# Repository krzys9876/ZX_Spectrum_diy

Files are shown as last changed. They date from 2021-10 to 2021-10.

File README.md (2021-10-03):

# ZX_Spectrum_diy

All boards that I designed, etched and soldered to create a full-diy replica of ZX Spectrum.
**Kicad4** (just a keyboard) and **Kicad5**

This is NOT a cycle-perfect replica so do not expect to launch fancy demos on it. 
The project started as a breadboard simplest possible computer using Z80. Quite quickly I started thinking of making a replica of ZX Spectrum - the first computer I ever used as a kid. All I wanted was to:

- launch Knight Lore - the best game ever
- write some Basic programs - to feel the magic of programming again - and I did!

Have questions? Just drop me an email.

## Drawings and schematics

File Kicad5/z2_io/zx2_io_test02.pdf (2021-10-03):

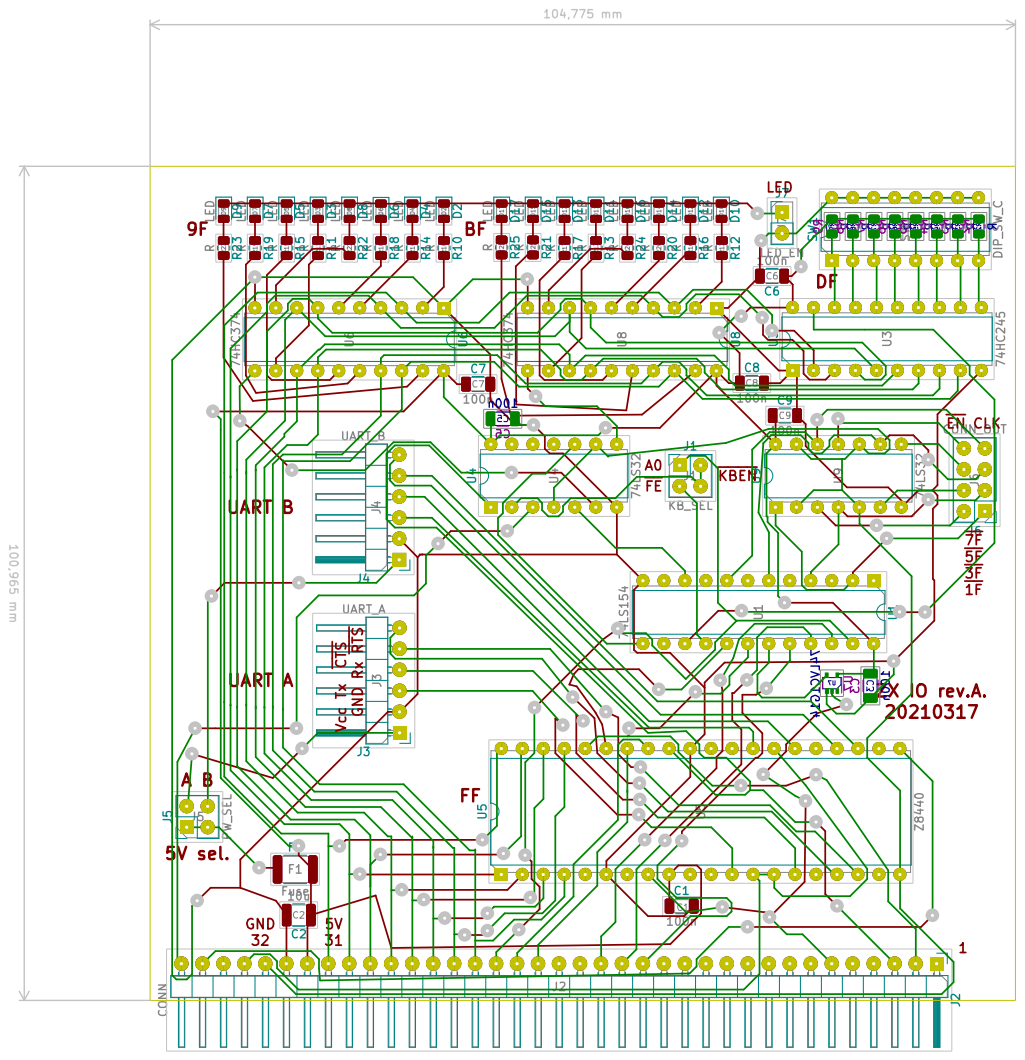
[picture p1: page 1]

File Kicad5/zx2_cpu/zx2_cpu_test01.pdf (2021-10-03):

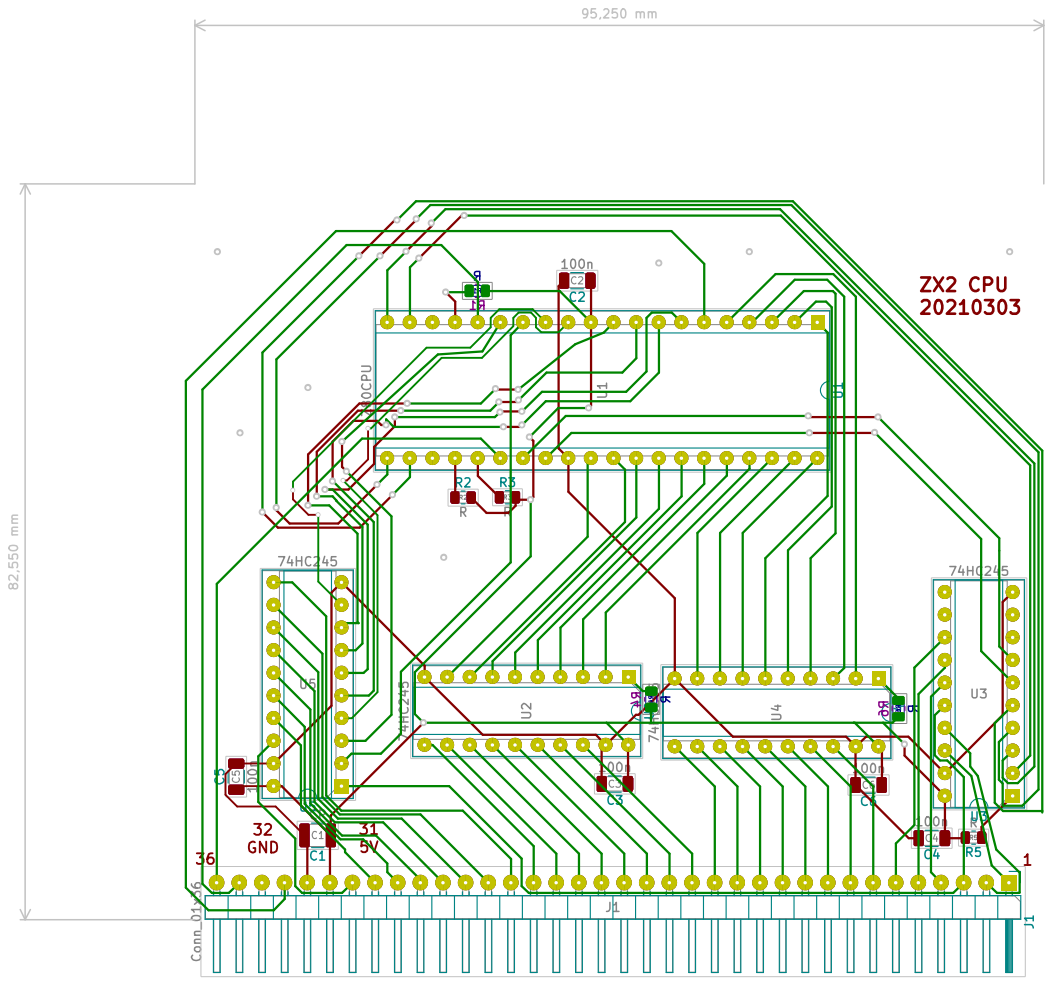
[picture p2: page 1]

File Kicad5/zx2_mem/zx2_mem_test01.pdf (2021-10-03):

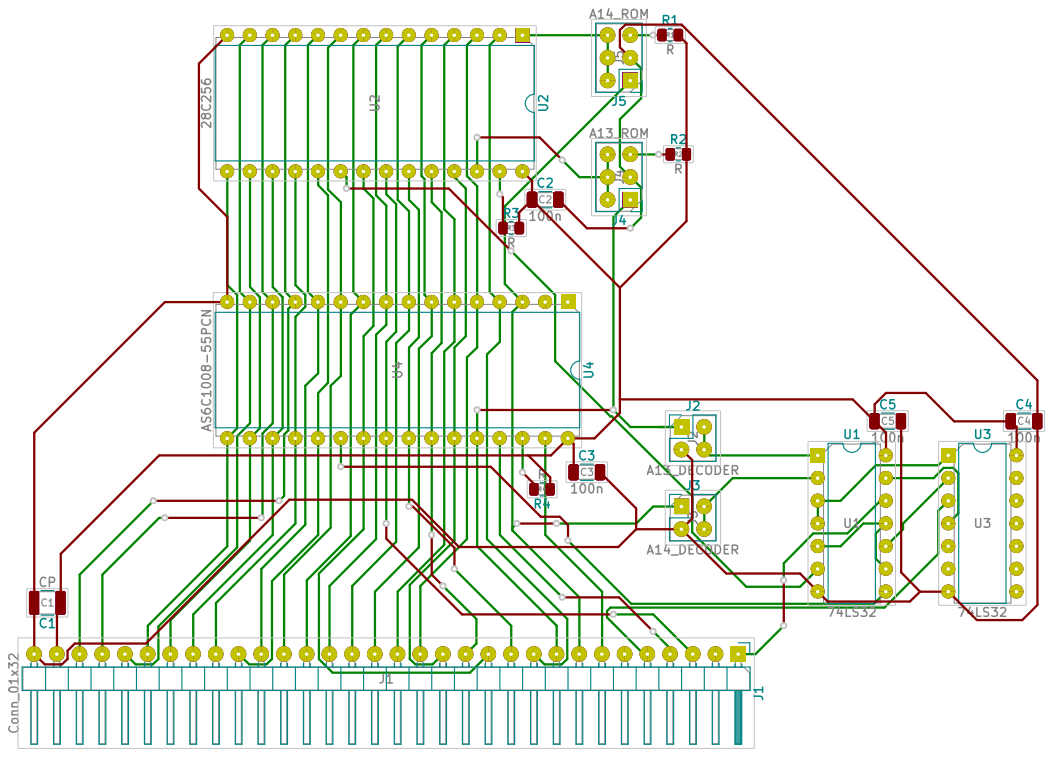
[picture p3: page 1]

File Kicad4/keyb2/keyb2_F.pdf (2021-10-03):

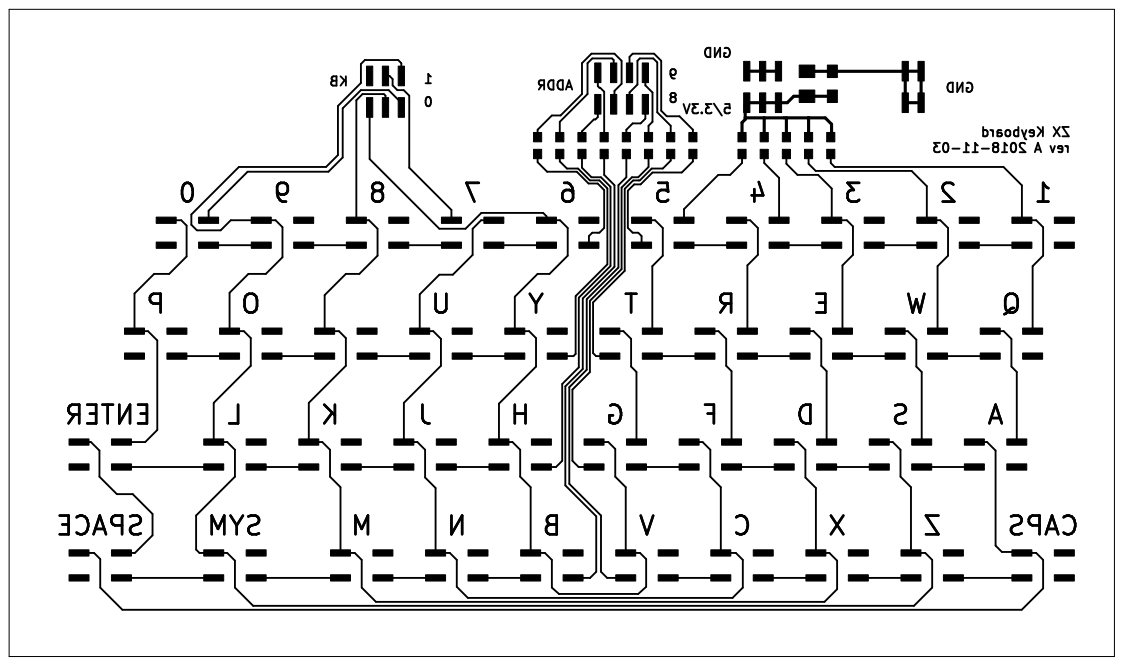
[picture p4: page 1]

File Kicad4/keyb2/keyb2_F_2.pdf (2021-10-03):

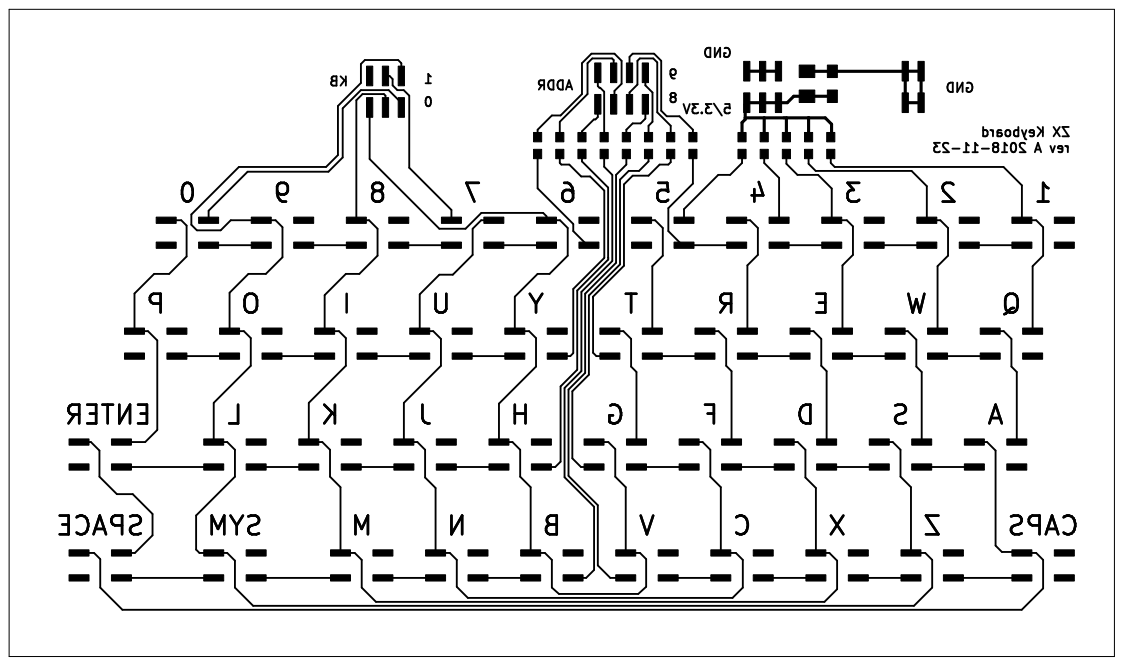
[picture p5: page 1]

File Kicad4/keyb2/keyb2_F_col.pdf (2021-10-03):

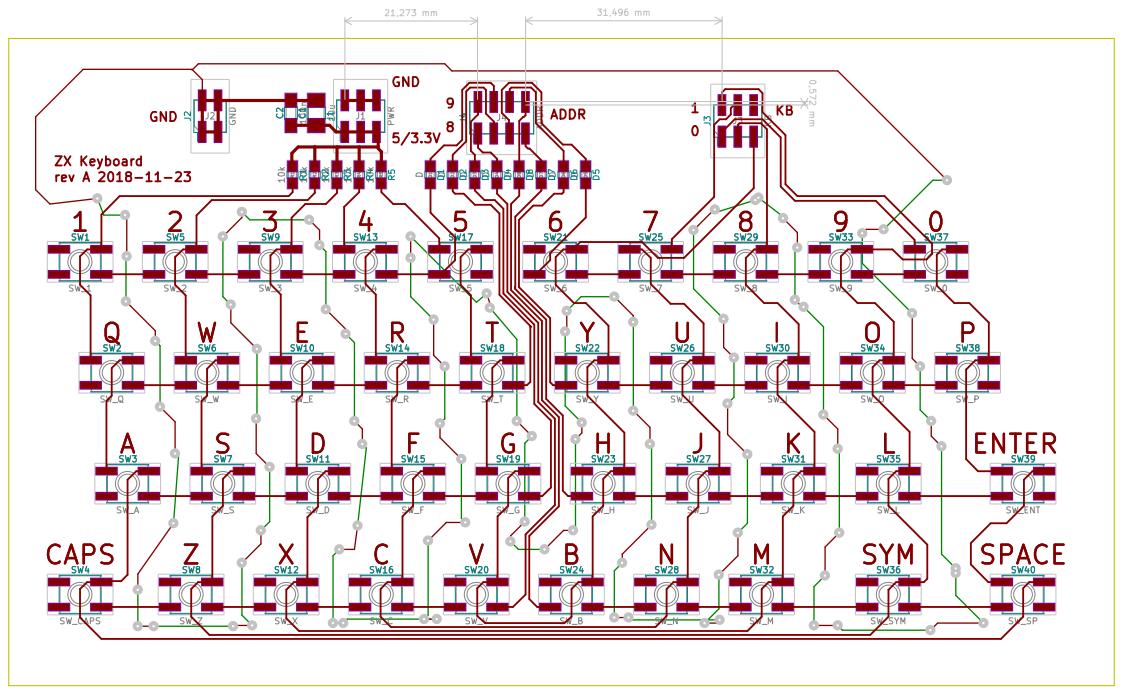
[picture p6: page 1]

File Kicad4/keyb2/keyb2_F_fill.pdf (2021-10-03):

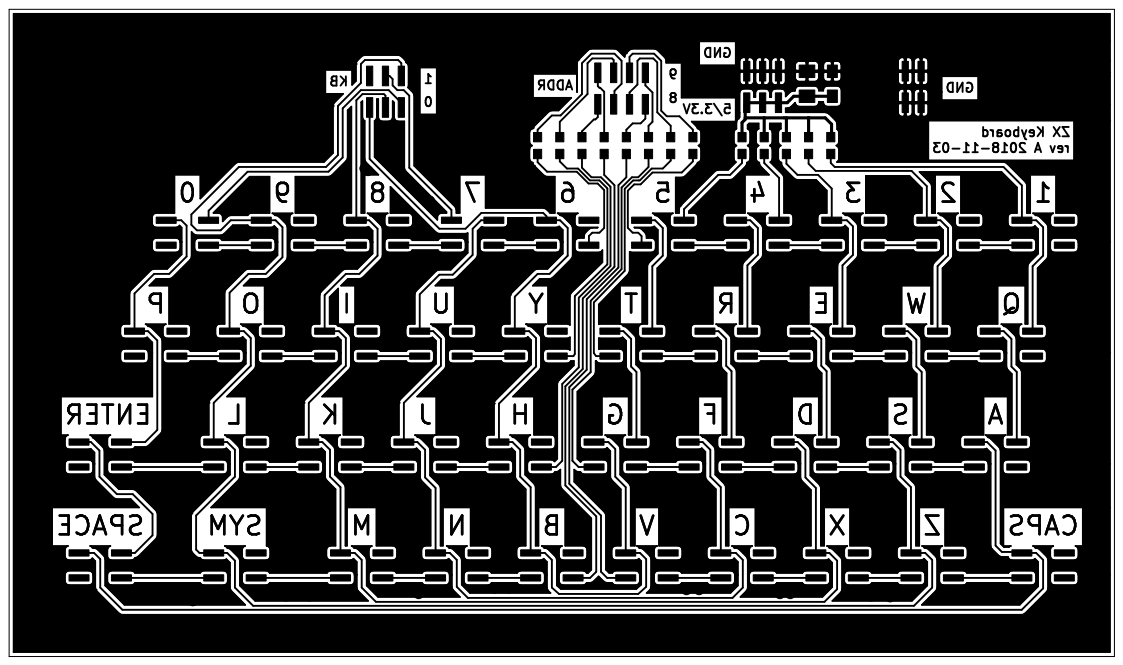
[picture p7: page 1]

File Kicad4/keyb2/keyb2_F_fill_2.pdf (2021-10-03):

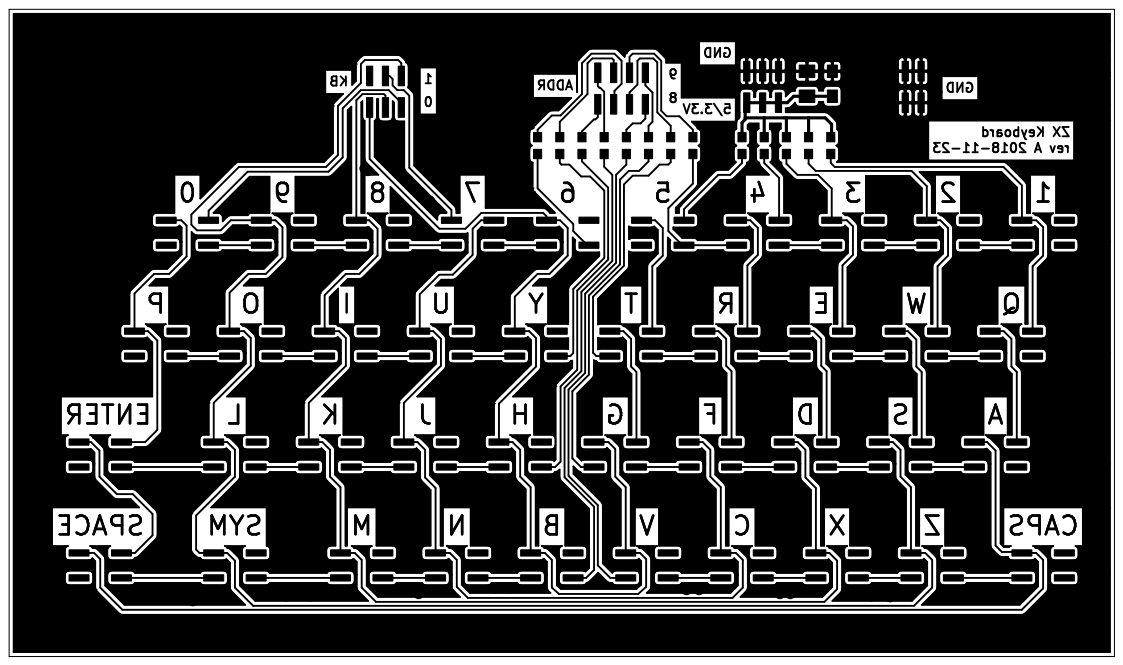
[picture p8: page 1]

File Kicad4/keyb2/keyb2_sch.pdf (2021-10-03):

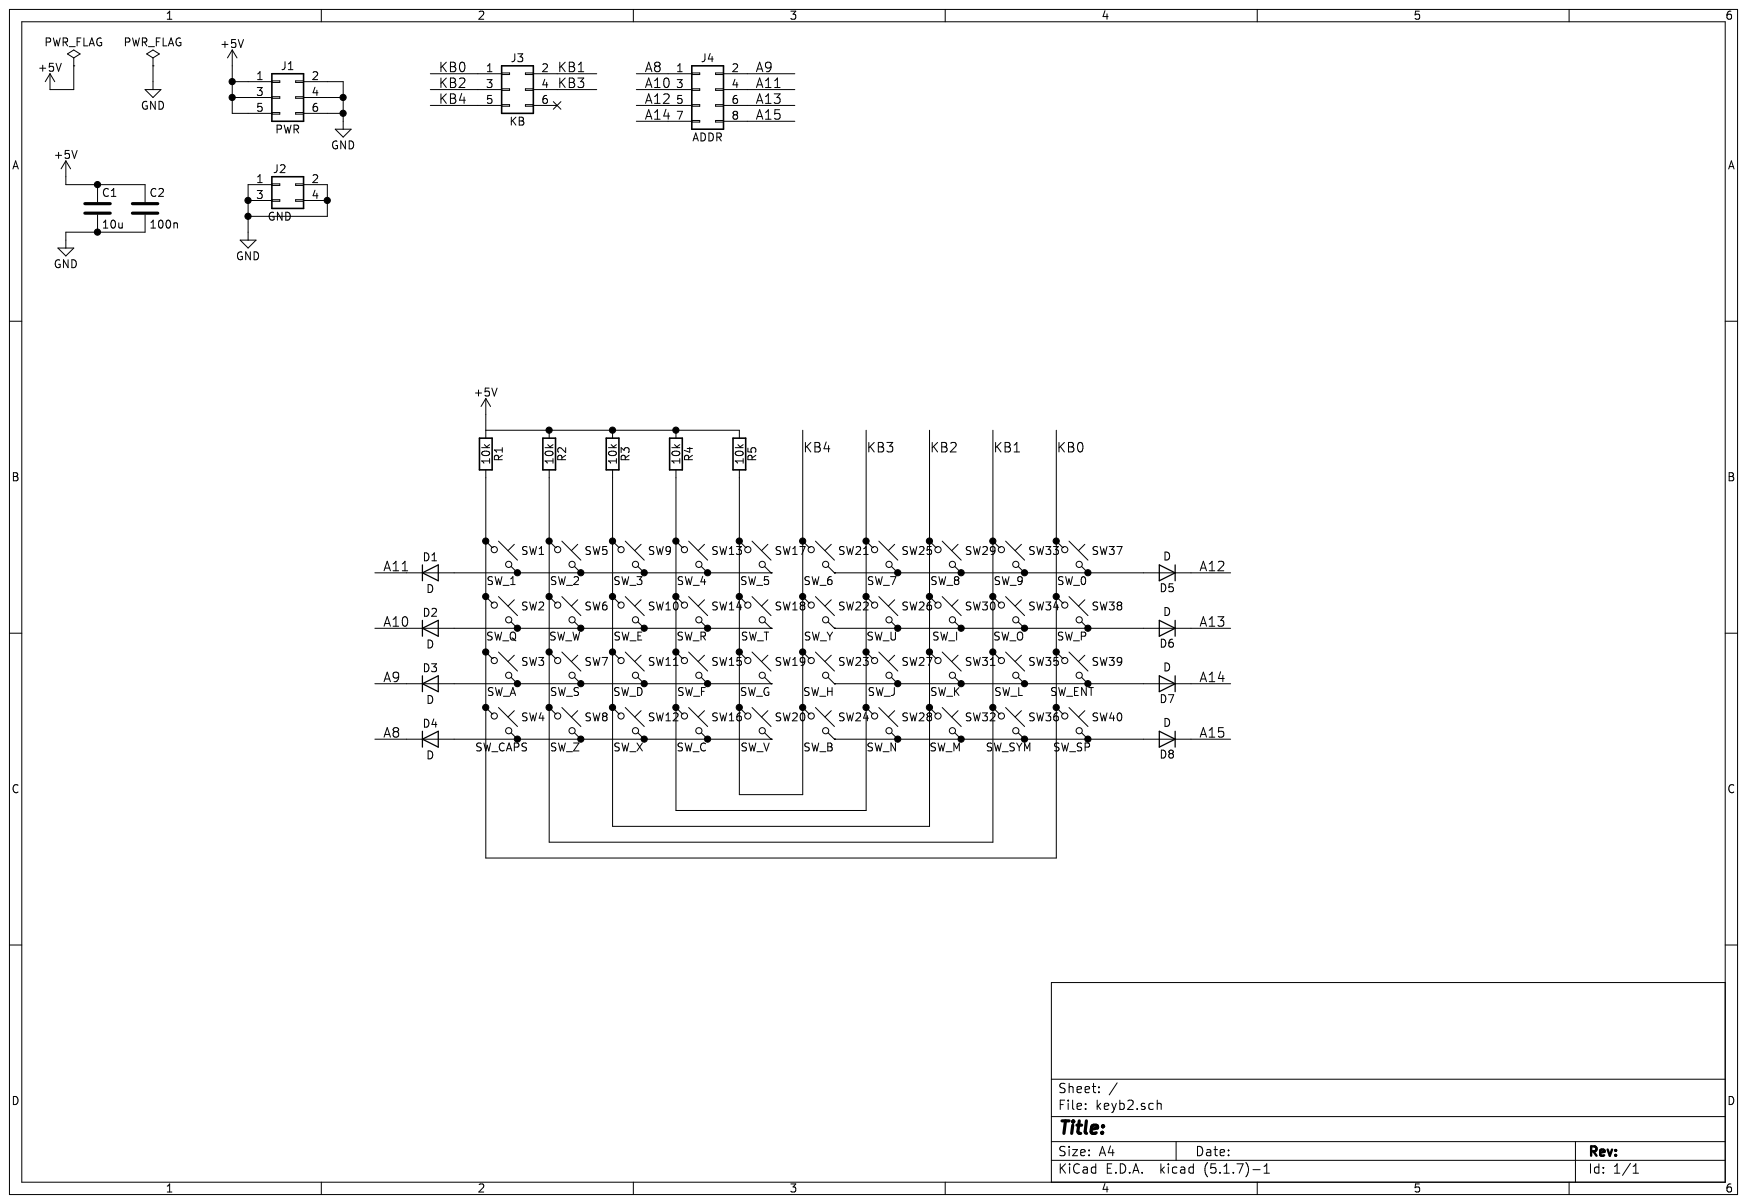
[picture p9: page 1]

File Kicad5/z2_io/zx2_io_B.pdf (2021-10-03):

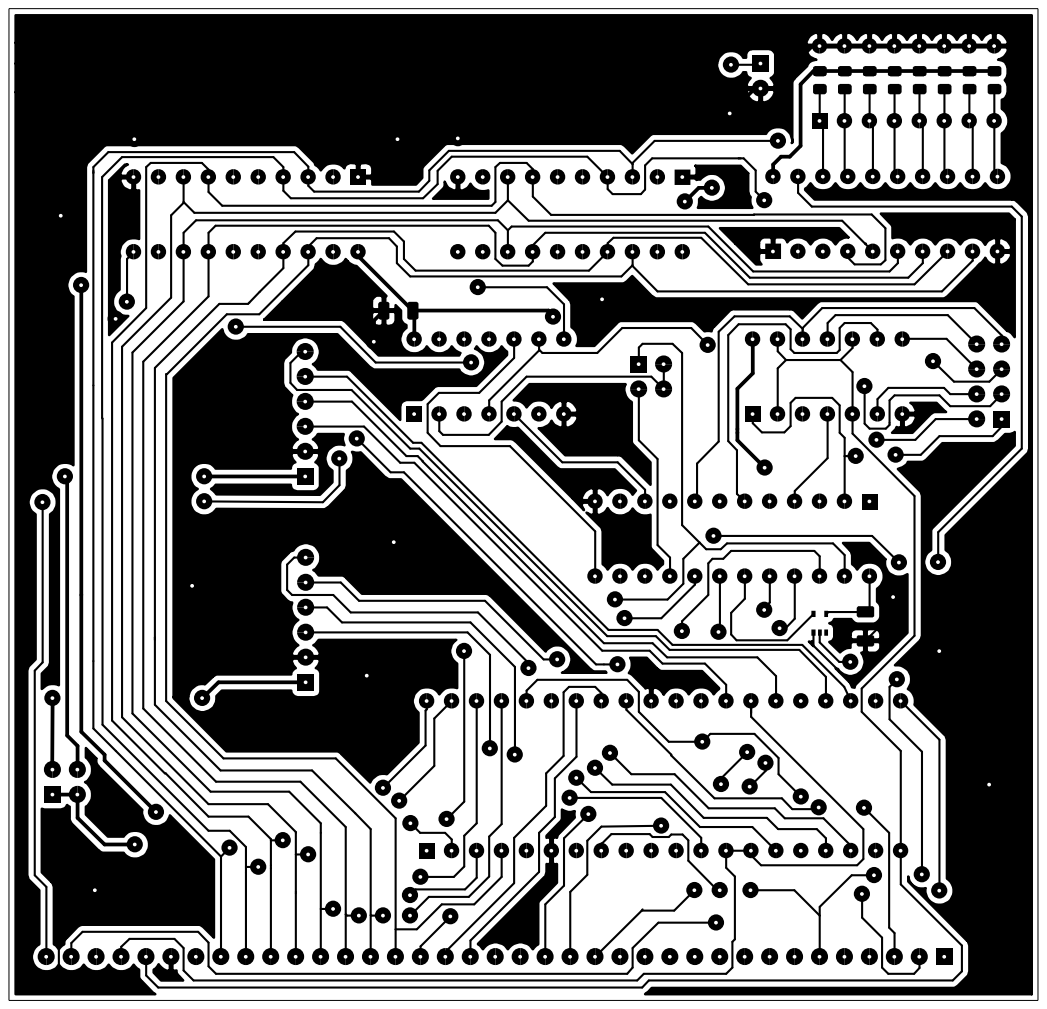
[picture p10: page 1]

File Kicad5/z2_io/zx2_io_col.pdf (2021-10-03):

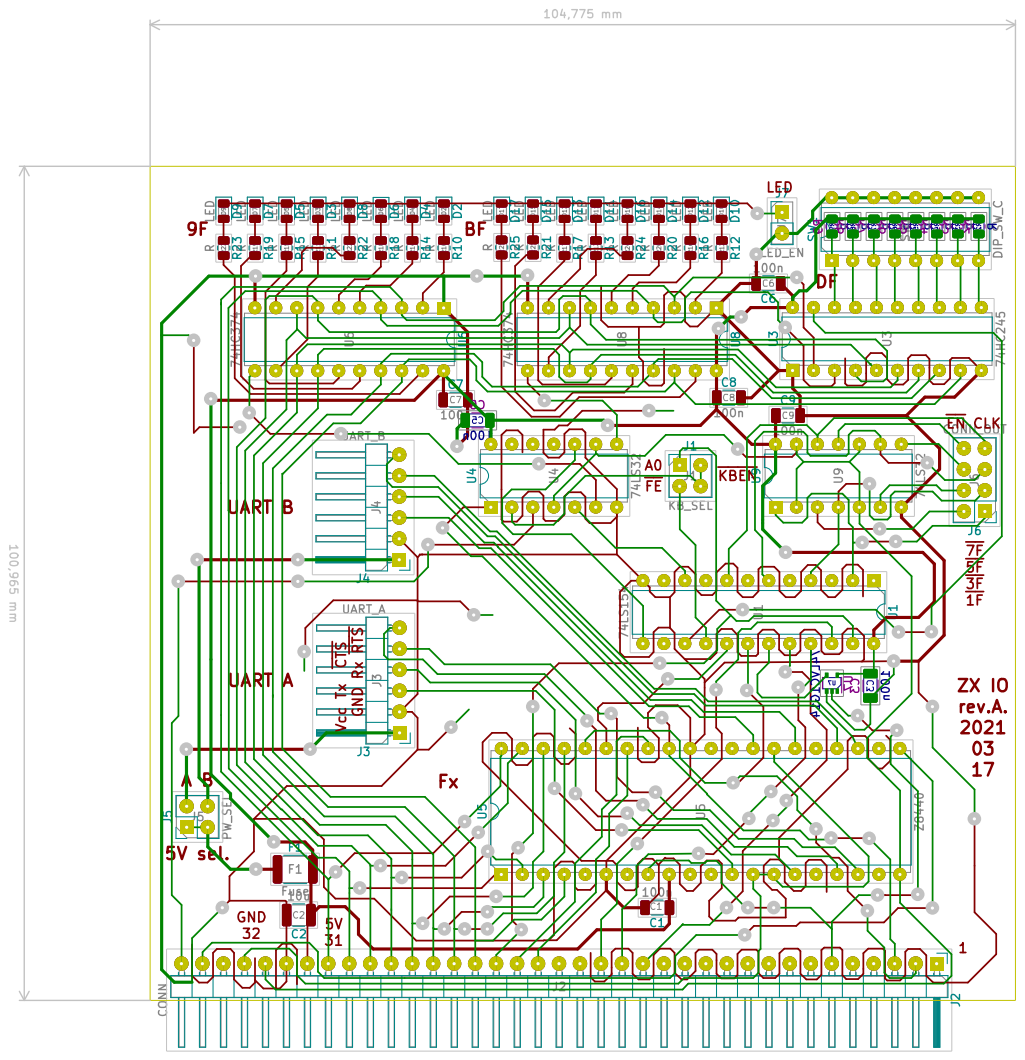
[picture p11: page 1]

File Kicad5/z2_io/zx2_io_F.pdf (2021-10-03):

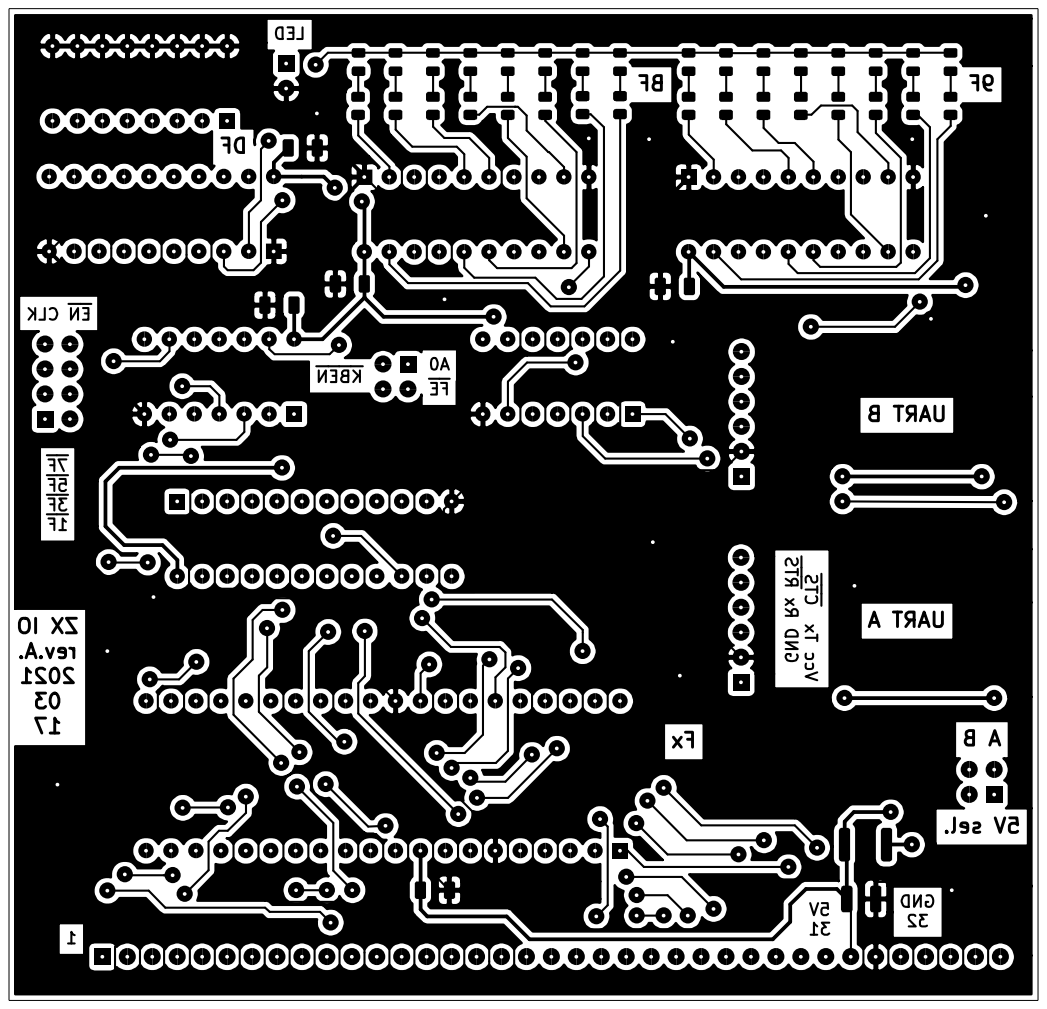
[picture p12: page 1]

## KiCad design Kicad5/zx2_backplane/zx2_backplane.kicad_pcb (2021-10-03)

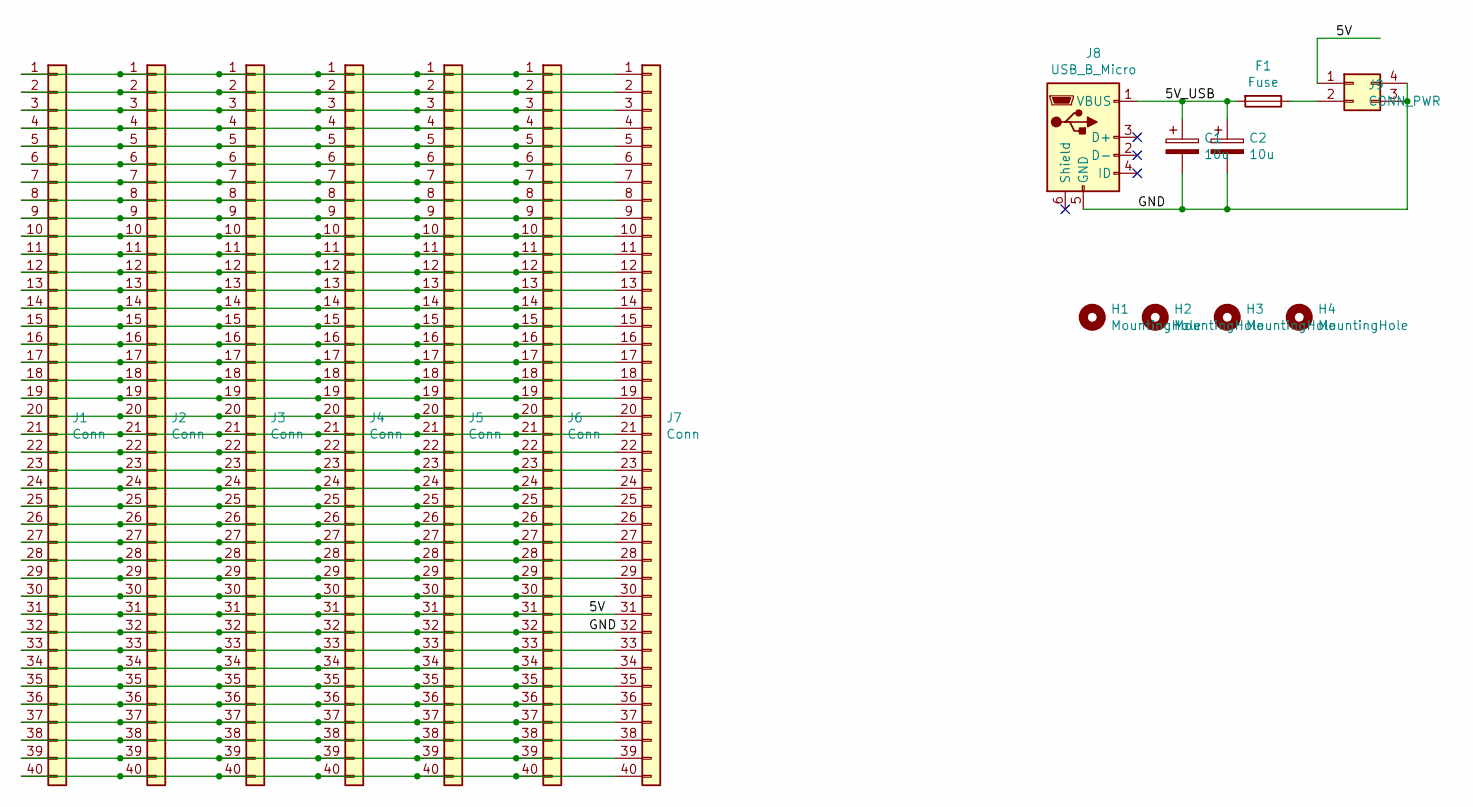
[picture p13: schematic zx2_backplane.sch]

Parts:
C1, C2: 10u; C_1210_3225Metric
F1: Fuse; Fuse_1812_4532Metric
H1, H2, H3, H4: MountingHole; MountingHole_3.2mm_M3
J1, J2, J3, J4, J5, J6, J7: Conn; PinHeader_1x40_P2.54mm_Vertical
J8: USB_B_Micro; USB_Micro-B_Amphenol_10104110_Horizontal
J9: CONN_PWR; PinHeader_2x02_P2.54mm_Vertical

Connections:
/5V: J1.31, J2.31, J3.31, J4.31, J5.31, J6.31, J7.31, J9.1
/5V_USB: C1.1, C2.1, F1.2, J8.1 (VBUS)
/GND: C1.2, C2.2, J1.32, J2.32, J3.32, J4.32, J5.32, J6.32, J7.32, J8.5 (GND), J9.3, J9.4
unnamed: F1.1, J9.2
unnamed: J1.1, J2.1, J3.1, J4.1, J5.1, J6.1, J7.1
unnamed: J1.2, J2.2, J3.2, J4.2, J5.2, J6.2, J7.2
unnamed: J1.3, J2.3, J3.3, J4.3, J5.3, J6.3, J7.3
unnamed: J1.4, J2.4, J3.4, J4.4, J5.4, J6.4, J7.4
unnamed: J1.5, J2.5, J3.5, J4.5, J5.5, J6.5, J7.5
unnamed: J1.6, J2.6, J3.6, J4.6, J5.6, J6.6, J7.6
unnamed: J1.7, J2.7, J3.7, J4.7, J5.7, J6.7, J7.7
unnamed: J1.8, J2.8, J3.8, J4.8, J5.8, J6.8, J7.8
unnamed: J1.9, J2.9, J3.9, J4.9, J5.9, J6.9, J7.9
unnamed: J1.10, J2.10, J3.10, J4.10, J5.10, J6.10, J7.10
unnamed: J1.11, J2.11, J3.11, J4.11, J5.11, J6.11, J7.11
unnamed: J1.12, J2.12, J3.12, J4.12, J5.12, J6.12, J7.12
unnamed: J1.13, J2.13, J3.13, J4.13, J5.13, J6.13, J7.13
unnamed: J1.14, J2.14, J3.14, J4.14, J5.14, J6.14, J7.14
unnamed: J1.15, J2.15, J3.15, J4.15, J5.15, J6.15, J7.15
unnamed: J1.16, J2.16, J3.16, J4.16, J5.16, J6.16, J7.16
unnamed: J1.17, J2.17, J3.17, J4.17, J5.17, J6.17, J7.17
unnamed: J1.18, J2.18, J3.18, J4.18, J5.18, J6.18, J7.18
unnamed: J1.19, J2.19, J3.19, J4.19, J5.19, J6.19, J7.19
unnamed: J1.20, J2.20, J3.20, J4.20, J5.20, J6.20, J7.20
unnamed: J1.21, J2.21, J3.21, J4.21, J5.21, J6.21, J7.21
unnamed: J1.22, J2.22, J3.22, J4.22, J5.22, J6.22, J7.22
unnamed: J1.23, J2.23, J3.23, J4.23, J5.23, J6.23, J7.23
unnamed: J1.24, J2.24, J3.24, J4.24, J5.24, J6.24, J7.24
unnamed: J1.25, J2.25, J3.25, J4.25, J5.25, J6.25, J7.25
unnamed: J1.26, J2.26, J3.26, J4.26, J5.26, J6.26, J7.26
unnamed: J1.27, J2.27, J3.27, J4.27, J5.27, J6.27, J7.27
unnamed: J1.28, J2.28, J3.28, J4.28, J5.28, J6.28, J7.28
unnamed: J1.29, J2.29, J3.29, J4.29, J5.29, J6.29, J7.29
unnamed: J1.30, J2.30, J3.30, J4.30, J5.30, J6.30, J7.30
unnamed: J1.33, J2.33, J3.33, J4.33, J5.33, J6.33, J7.33
unnamed: J1.34, J2.34, J3.34, J4.34, J5.34, J6.34, J7.34
unnamed: J1.35, J2.35, J3.35, J4.35, J5.35, J6.35, J7.35
unnamed: J1.36, J2.36, J3.36, J4.36, J5.36, J6.36, J7.36
unnamed: J1.37, J2.37, J3.37, J4.37, J5.37, J6.37, J7.37
unnamed: J1.38, J2.38, J3.38, J4.38, J5.38, J6.38, J7.38
unnamed: J1.39, J2.39, J3.39, J4.39, J5.39, J6.39, J7.39
unnamed: J1.40, J2.40, J3.40, J4.40, J5.40, J6.40, J7.40

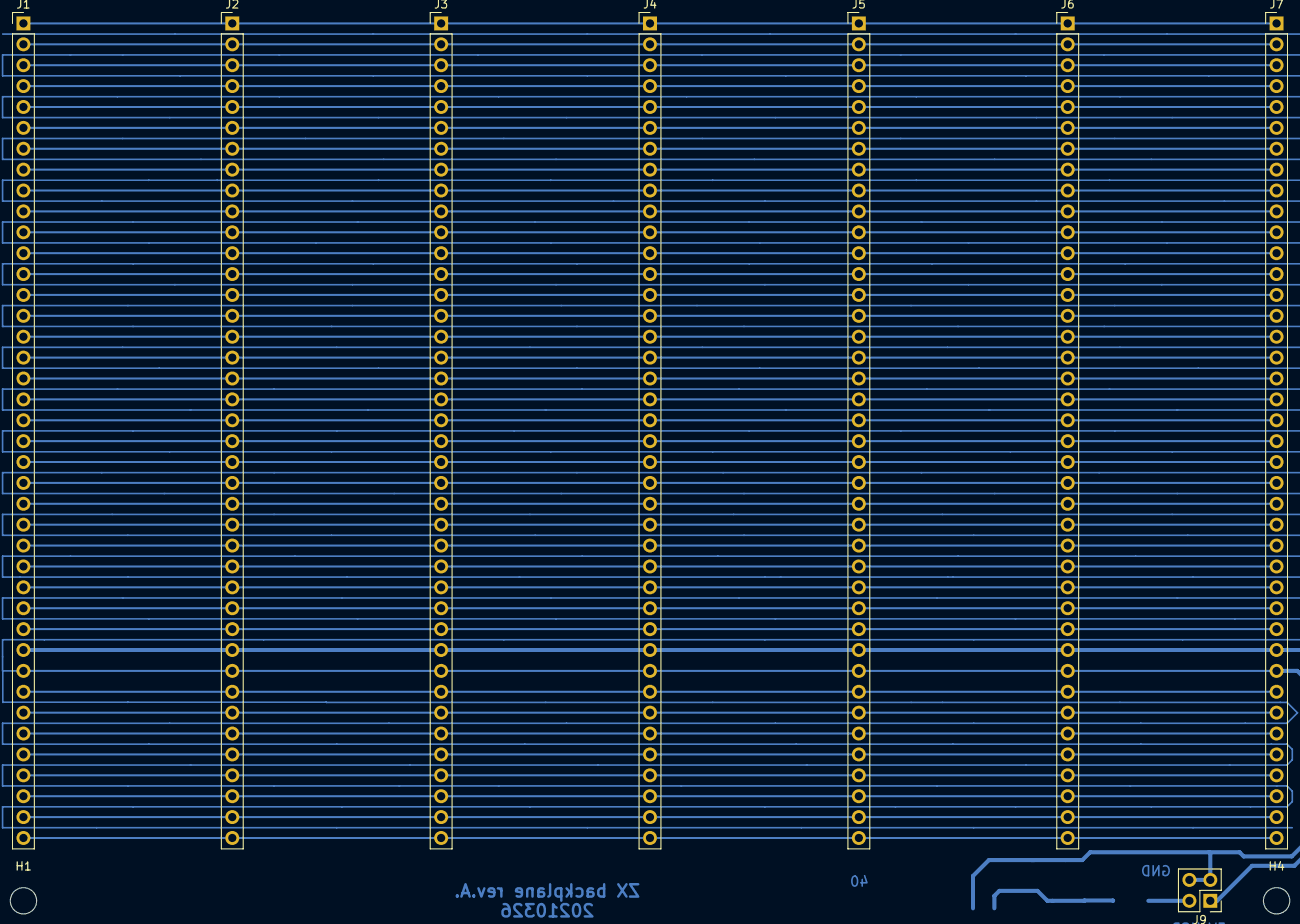
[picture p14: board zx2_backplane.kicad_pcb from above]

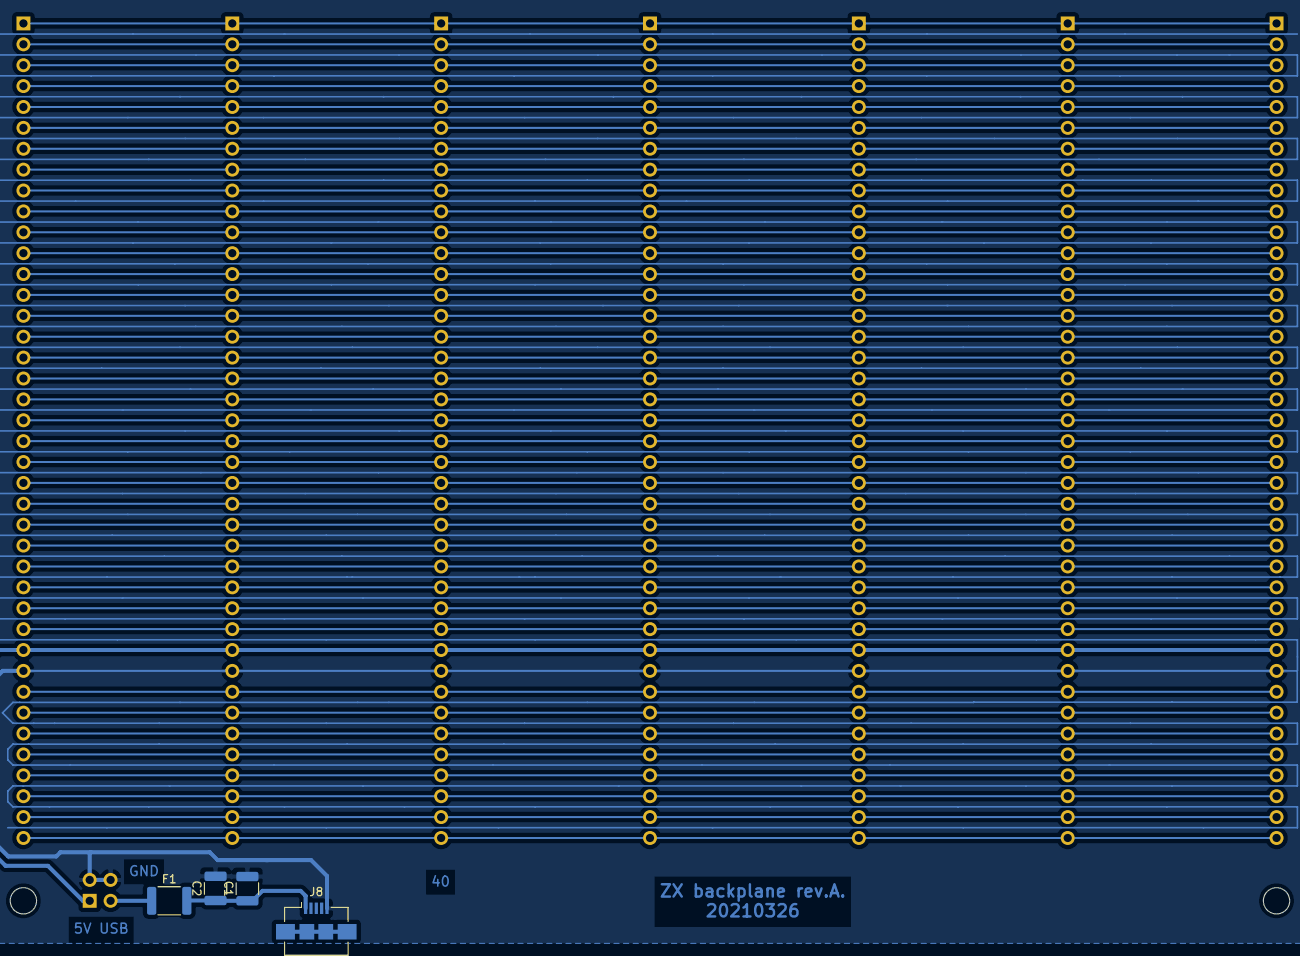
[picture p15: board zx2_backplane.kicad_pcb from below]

Board: 2 copper layers, 16 parts (4 on the bottom side), 42 nets.

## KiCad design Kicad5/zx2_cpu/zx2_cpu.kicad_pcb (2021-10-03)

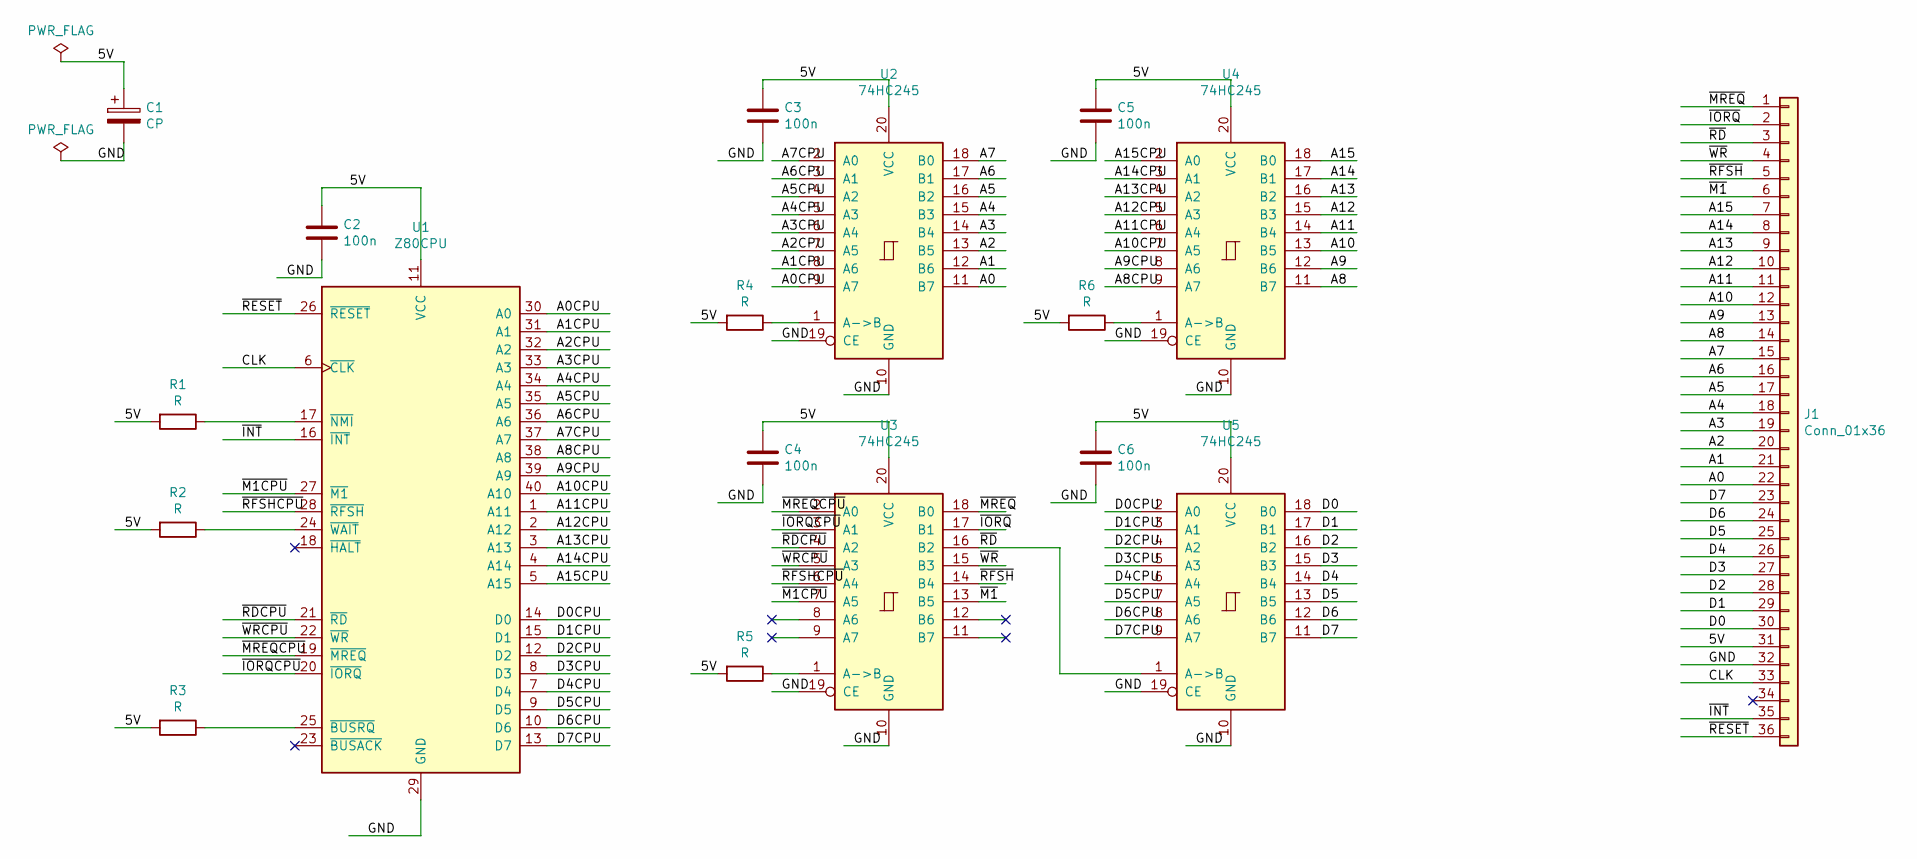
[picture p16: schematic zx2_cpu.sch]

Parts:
C1: CP; C_1210_3225Metric
C2, C3, C4, C5, C6: 100n; C_1206_3216Metric
J1: Conn_01x36; PinHeader_1x36_P2.54mm_Horizontal
R1, R2, R3, R4, R5, R6: R; R_0805_2012Metric
U1: Z80CPU; DIP-40_W15.24mm_Socket
U2, U3, U4, U5: 74HC245; DIP-20_W7.62mm_Socket

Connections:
/5V: C1.1, C2.1, C3.1, C4.1, C5.1, C6.1, J1.31, R1.2, R2.2, R3.2, R4.2, R5.2, R6.2, U1.11 (VCC), U2.20 (VCC), U3.20 (VCC), U4.20 (VCC), U5.20 (VCC)
/A0: J1.22, U2.11 (B7)
/A0CPU: U1.30 (A0), U2.9 (A7)
/A1: J1.21, U2.12 (B6)
/A1CPU: U1.31 (A1), U2.8 (A6)
/A2: J1.20, U2.13 (B5)
/A2CPU: U1.32 (A2), U2.7 (A5)
/A3: J1.19, U2.14 (B4)
/A3CPU: U1.33 (A3), U2.6 (A4)
/A4: J1.18, U2.15 (B3)
/A4CPU: U1.34 (A4), U2.5 (A3)
/A5: J1.17, U2.16 (B2)
/A5CPU: U1.35 (A5), U2.4 (A2)
/A6: J1.16, U2.17 (B1)
/A6CPU: U1.36 (A6), U2.3 (A1)
/A7: J1.15, U2.18 (B0)
/A7CPU: U1.37 (A7), U2.2 (A0)
/A8: J1.14, U4.11 (B7)
/A8CPU: U1.38 (A8), U4.9 (A7)
/A9: J1.13, U4.12 (B6)
/A9CPU: U1.39 (A9), U4.8 (A6)
/A10: J1.12, U4.13 (B5)
/A10CPU: U1.40 (A10), U4.7 (A5)
/A11: J1.11, U4.14 (B4)
/A11CPU: U1.1 (A11), U4.6 (A4)
/A12: J1.10, U4.15 (B3)
/A12CPU: U1.2 (A12), U4.5 (A3)
/A13: J1.9, U4.16 (B2)
/A13CPU: U1.3 (A13), U4.4 (A2)
/A14: J1.8, U4.17 (B1)
/A14CPU: U1.4 (A14), U4.3 (A1)
/A15: J1.7, U4.18 (B0)
/A15CPU: U1.5 (A15), U4.2 (A0)
/CLK: J1.33, U1.6 (~CLK~)
/D0: J1.30, U5.18 (B0)
/D0CPU: U1.14 (D0), U5.2 (A0)
/D1: J1.29, U5.17 (B1)
/D1CPU: U1.15 (D1), U5.3 (A1)
/D2: J1.28, U5.16 (B2)
/D2CPU: U1.12 (D2), U5.4 (A2)
/D3: J1.27, U5.15 (B3)
/D3CPU: U1.8 (D3), U5.5 (A3)
/D4: J1.26, U5.14 (B4)
/D4CPU: U1.7 (D4), U5.6 (A4)
/D5: J1.25, U5.13 (B5)
/D5CPU: U1.9 (D5), U5.7 (A5)
/D6: J1.24, U5.12 (B6)
/D6CPU: U1.10 (D6), U5.8 (A6)
/D7: J1.23, U5.11 (B7)
/D7CPU: U1.13 (D7), U5.9 (A7)
/GND: C1.2, C2.2, C3.2, C4.2, C5.2, C6.2, J1.32, U1.29 (GND), U2.10 (GND), U2.19 (CE), U3.10 (GND), U3.19 (CE), U4.10 (GND), U4.19 (CE), U5.10 (GND), U5.19 (CE)
/~INT: J1.35, U1.16 (~INT~)
/~IORQ: J1.2, U3.17 (B1)
/~IORQCPU: U1.20 (~IORQ~), U3.3 (A1)
/~M1: J1.6, U3.13 (B5)
/~M1CPU: U1.27 (~M1~), U3.7 (A5)
/~MREQ: J1.1, U3.18 (B0)
/~MREQCPU: U1.19 (~MREQ~), U3.2 (A0)
/~RD: J1.3, U3.16 (B2), U5.1 (A->B)
/~RDCPU: U1.21 (~RD~), U3.4 (A2)
/~RESET: J1.36, U1.26 (~RESET~)
/~RFSH: J1.5, U3.14 (B4)
/~RFSHCPU: U1.28 (~RFSH~), U3.6 (A4)
/~WR: J1.4, U3.15 (B3)
/~WRCPU: U1.22 (~WR~), U3.5 (A3)
unnamed: R1.1, U1.17 (~NMI~)
unnamed: R2.1, U1.24 (~WAIT~)
unnamed: R3.1, U1.25 (~BUSRQ~)
unnamed: R4.1, U2.1 (A->B)
unnamed: R5.1, U3.1 (A->B)
unnamed: R6.1, U4.1 (A->B)

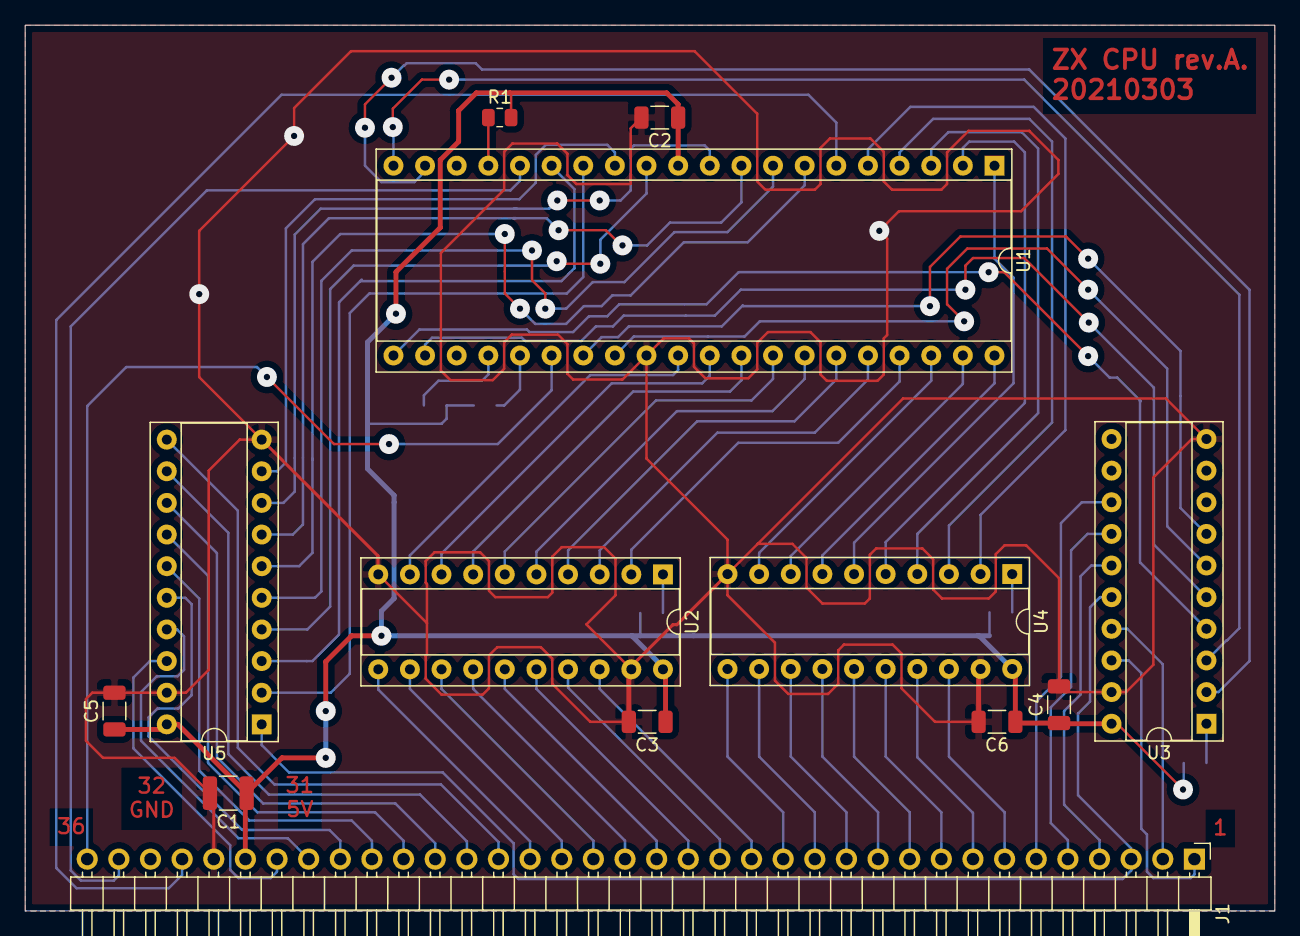
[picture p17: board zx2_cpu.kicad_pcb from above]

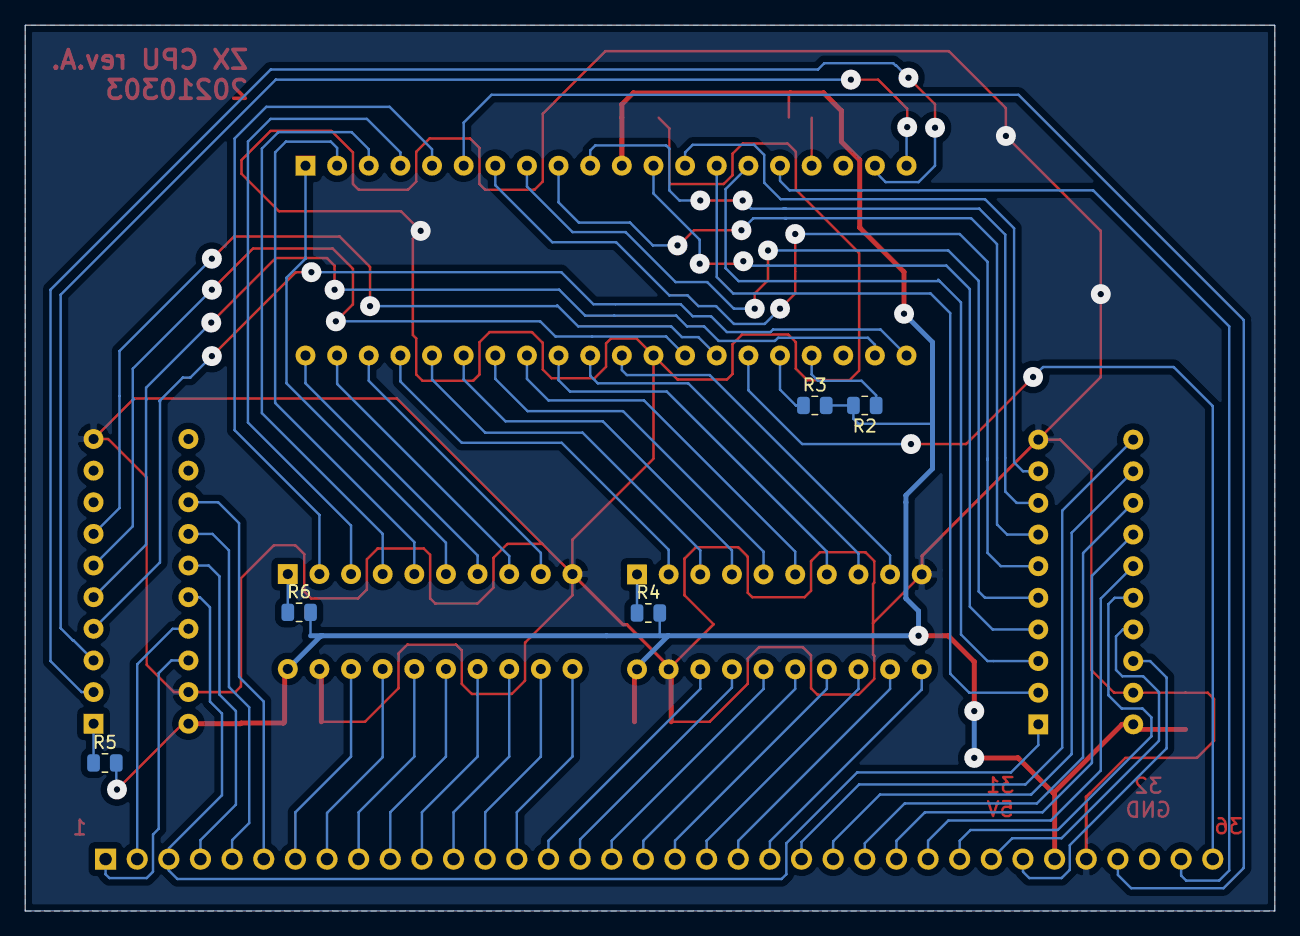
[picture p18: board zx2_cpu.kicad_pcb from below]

Board: 2 copper layers, 100.3 x 71.1 mm, 18 parts (5 on the bottom side), 71 nets.

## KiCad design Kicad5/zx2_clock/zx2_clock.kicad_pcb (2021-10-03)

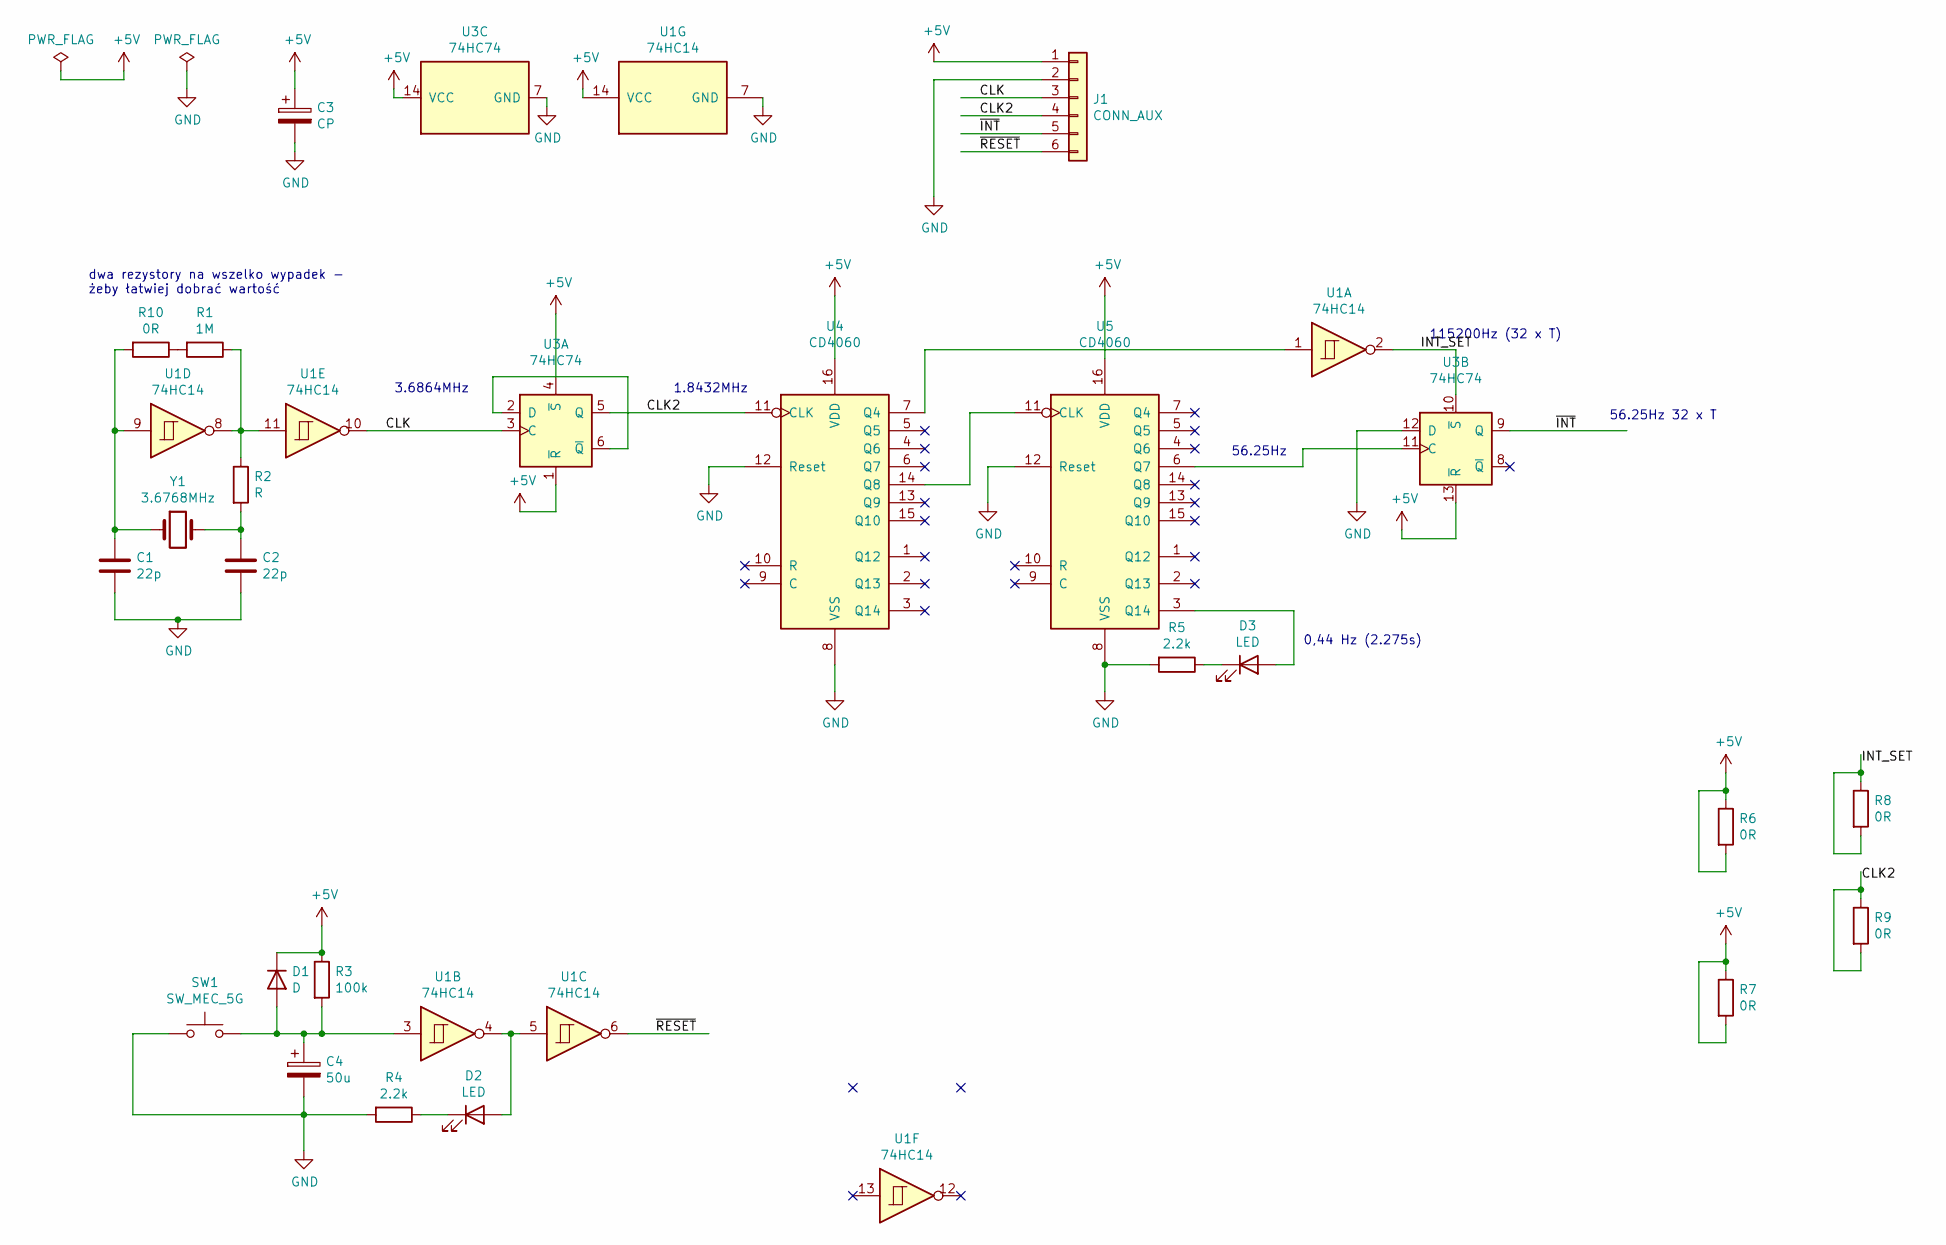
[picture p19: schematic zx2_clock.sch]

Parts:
C1, C2: 22p; C_0603_1608Metric
C3: CP; C_1210_3225Metric
C4: 50u; CP_Elec_5x3
D1: D; C_0805_2012Metric
D2, D3: LED; C_0805_2012Metric
J1: CONN_AUX; PinHeader_1x06_P2.54mm_Horizontal
R1: 1M; C_0805_2012Metric
R2: R; C_0805_2012Metric
R3: 100k; C_0805_2012Metric
R4, R5: 2.2k; C_0805_2012Metric
R6, R7, R8, R9: 0R; R_1206_3216Metric
R10: 0R; C_0805_2012Metric
SW1: SW_MEC_5G; SW_SPST_EVQPE1
U1: 74HC14; DIP-14_W7.62mm
U3: 74HC74; DIP-14_W7.62mm
U4, U5: CD4060; DIP-16_W7.62mm
Y1: 3.6768MHz; Crystal_SMD_HC49-SD

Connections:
+5V: C3.1, D1.1 (K), J1.1, R3.1, R6.1, R6.2, R7.1, R7.2, U1.14 (VCC), U3.1 (~R), U3.4 (~S), U3.13 (~R), U3.14 (VCC), U4.16 (VDD), U5.16 (VDD)
/CLK: J1.3, U1.10, U3.3 (C)
/CLK2: J1.4, R9.1, R9.2, U3.5 (Q), U4.11 (CLK)
/INT_SET: R8.1, R8.2, U1.2, U3.10 (~S)
/~INT: J1.5, U3.9 (Q)
/~RESET: J1.6, U1.6
GND: C1.2, C2.2, C3.2, C4.2, J1.2, R4.2, R5.2, SW1.1, U1.7 (GND), U3.7 (GND), U3.12 (D), U4.8 (VSS), U4.12 (Reset), U5.8 (VSS), U5.12 (Reset)
unnamed: C1.1, R10.2, U1.9, Y1.1
unnamed: C2.1, R2.2, Y1.2
unnamed: C4.1, D1.2 (A), R3.2, SW1.2, U1.3
unnamed: D2.1 (K), R4.1
unnamed: D2.2 (A), U1.4, U1.5
unnamed: D3.1 (K), R5.1
unnamed: D3.2 (A), U5.3 (Q14)
unnamed: R1.1, R2.1, U1.8, U1.11
unnamed: R1.2, R10.1
unnamed: U1.1, U4.7 (Q4)
unnamed: U3.2 (D), U3.6 (~Q)
unnamed: U3.11 (C), U5.6 (Q7)
unnamed: U4.14 (Q8), U5.11 (CLK)

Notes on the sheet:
56.25Hz
115200Hz (32 x T)
3.6864MHz
1.8432MHz
56.25Hz 32 x T
0,44 Hz (2.275s)
dwa rezystory na wszelko wypadek - żeby łatwiej dobrać wartość

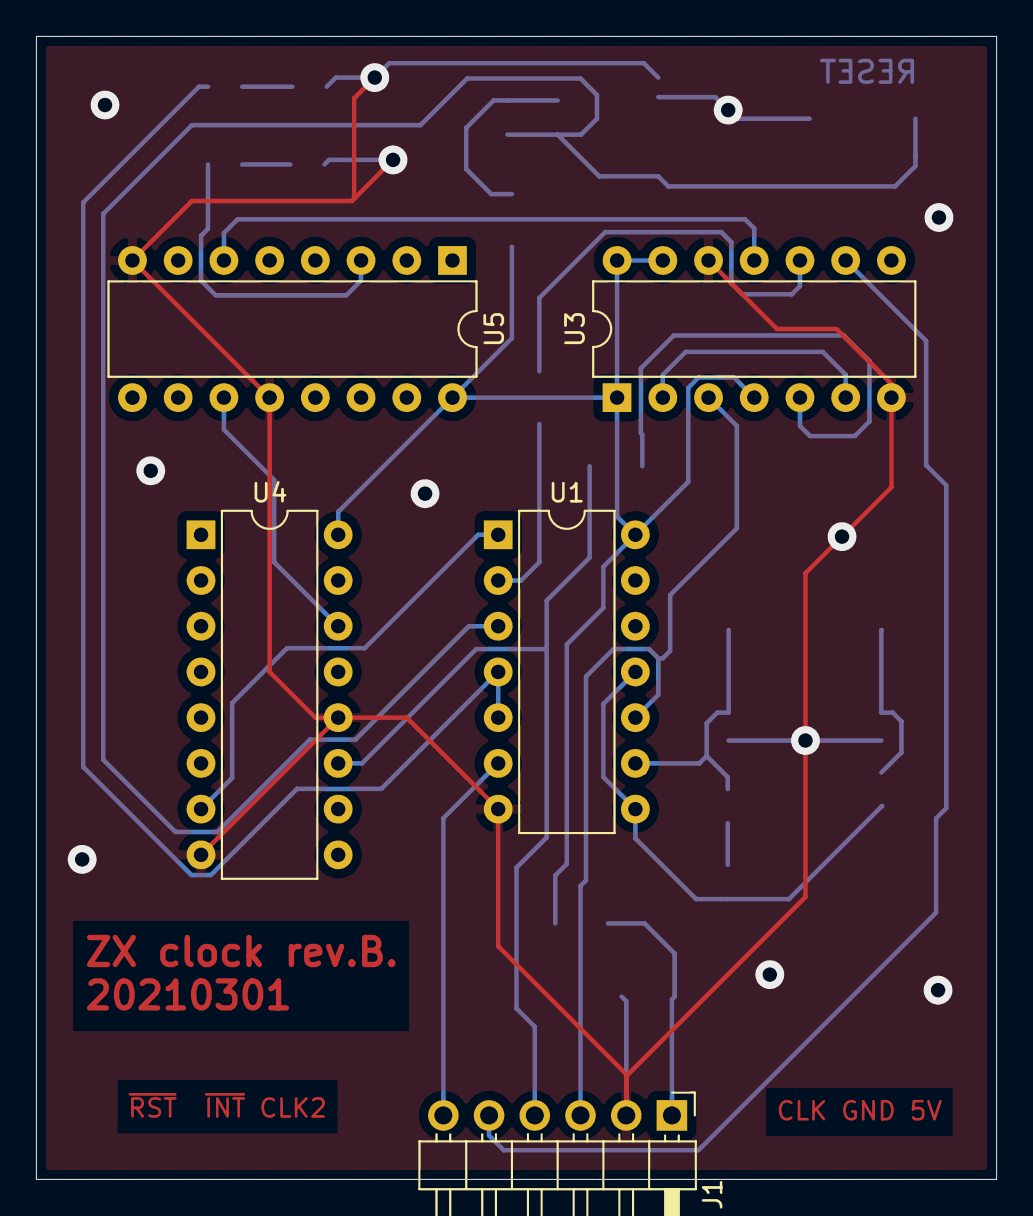
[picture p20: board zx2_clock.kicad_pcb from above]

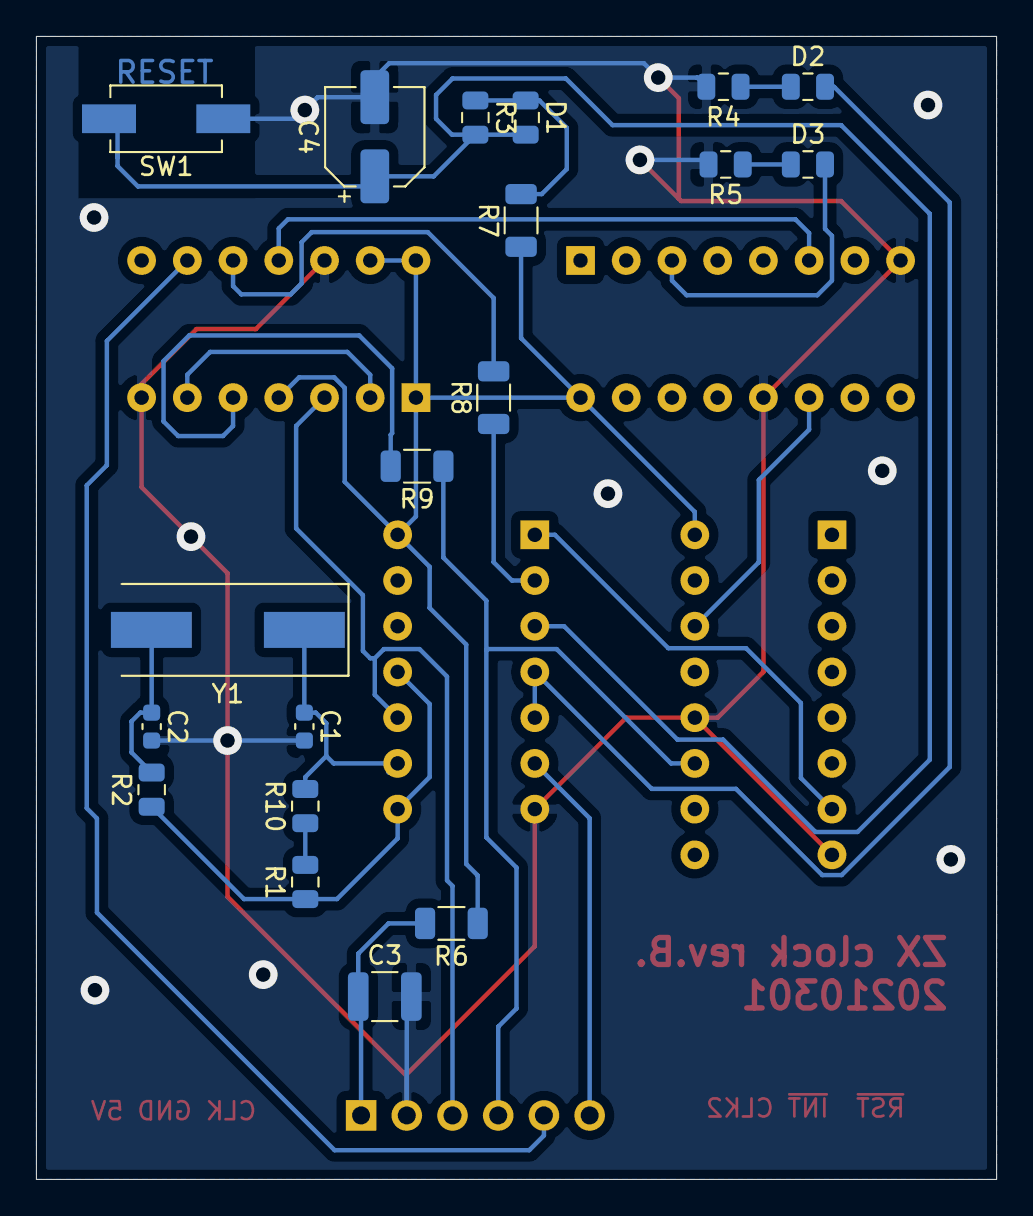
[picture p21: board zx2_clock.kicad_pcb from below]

Board: 2 copper layers, 53.3 x 63.5 mm, 24 parts (19 on the bottom side), 20 nets.

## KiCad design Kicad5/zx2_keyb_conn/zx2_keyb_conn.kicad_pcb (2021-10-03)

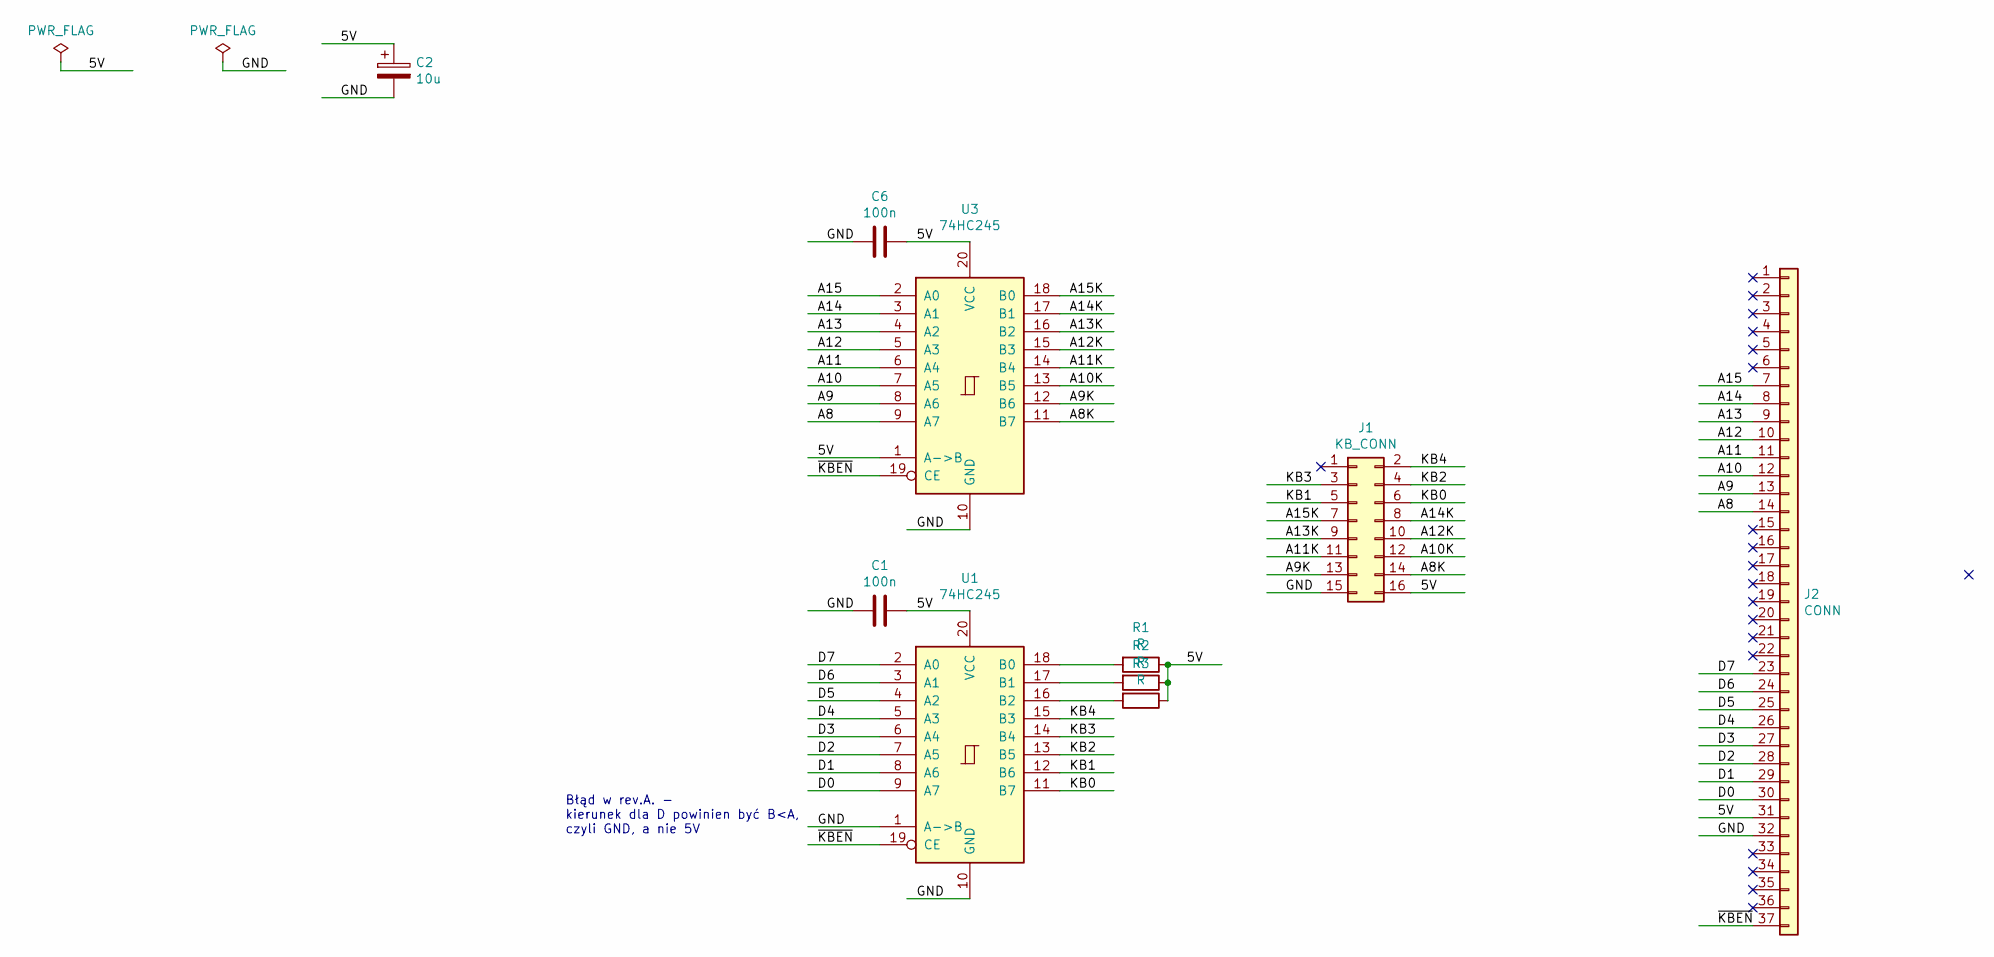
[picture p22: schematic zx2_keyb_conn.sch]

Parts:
C1, C6: 100n; C_1206_3216Metric
C2: 10u; C_1210_3225Metric
J1: KB_CONN; PinHeader_2x08_P2.54mm_Vertical
J2: CONN; PinHeader_1x37_P2.54mm_Horizontal
R1, R2, R3: R; R_0805_2012Metric
U1, U3: 74HC245; SO-20_12.8x7.5mm_P1.27mm

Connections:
/5V: C1.1, C2.1, C6.1, J1.16, J2.31, R1.1, R2.1, R3.1, U1.20 (VCC), U3.1 (A->B), U3.20 (VCC)
/A8: J2.14, U3.9 (A7)
/A8K: J1.14, U3.11 (B7)
/A9: J2.13, U3.8 (A6)
/A9K: J1.13, U3.12 (B6)
/A10: J2.12, U3.7 (A5)
/A10K: J1.12, U3.13 (B5)
/A11: J2.11, U3.6 (A4)
/A11K: J1.11, U3.14 (B4)
/A12: J2.10, U3.5 (A3)
/A12K: J1.10, U3.15 (B3)
/A13: J2.9, U3.4 (A2)
/A13K: J1.9, U3.16 (B2)
/A14: J2.8, U3.3 (A1)
/A14K: J1.8, U3.17 (B1)
/A15: J2.7, U3.2 (A0)
/A15K: J1.7, U3.18 (B0)
/D0: J2.30, U1.9 (A7)
/D1: J2.29, U1.8 (A6)
/D2: J2.28, U1.7 (A5)
/D3: J2.27, U1.6 (A4)
/D4: J2.26, U1.5 (A3)
/D5: J2.25, U1.4 (A2)
/D6: J2.24, U1.3 (A1)
/D7: J2.23, U1.2 (A0)
/GND: C1.2, C2.2, C6.2, J1.15, J2.32, U1.1 (A->B), U1.10 (GND), U3.10 (GND)
/KB0: J1.6, U1.11 (B7)
/KB1: J1.5, U1.12 (B6)
/KB2: J1.4, U1.13 (B5)
/KB3: J1.3, U1.14 (B4)
/KB4: J1.2, U1.15 (B3)
/~KBEN: J2.37, U1.19 (CE), U3.19 (CE)
unnamed: R1.2, U1.18 (B0)
unnamed: R2.2, U1.17 (B1)
unnamed: R3.2, U1.16 (B2)

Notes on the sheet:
Błąd w rev.A. - kierunek dla D powinien być B<A, czyli GND, a nie 5V

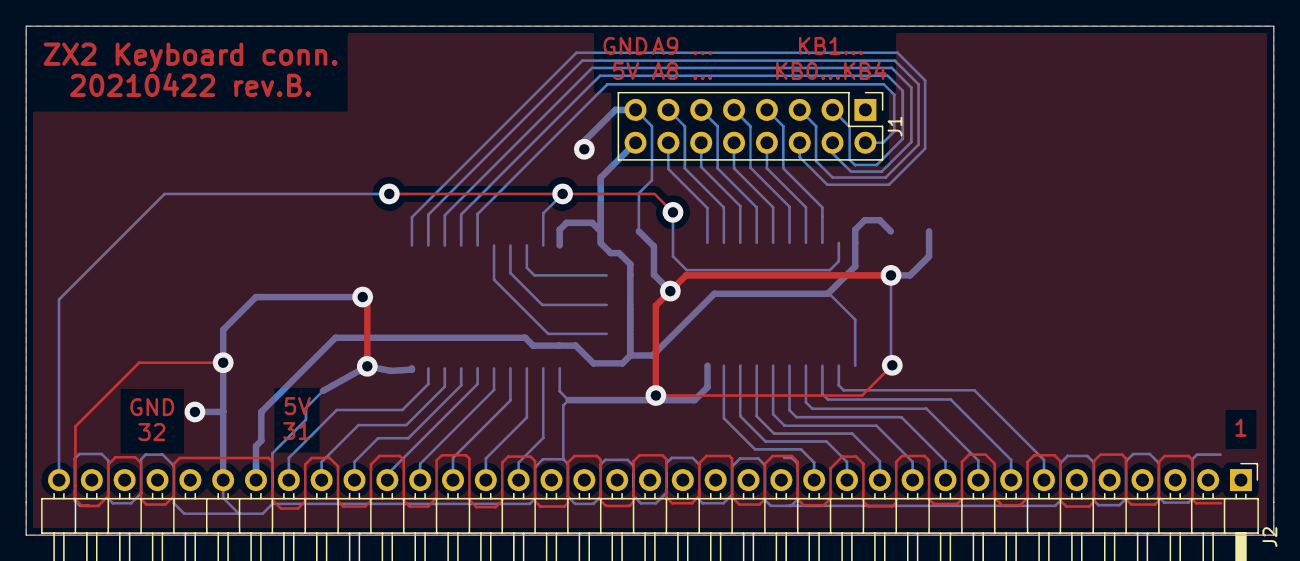
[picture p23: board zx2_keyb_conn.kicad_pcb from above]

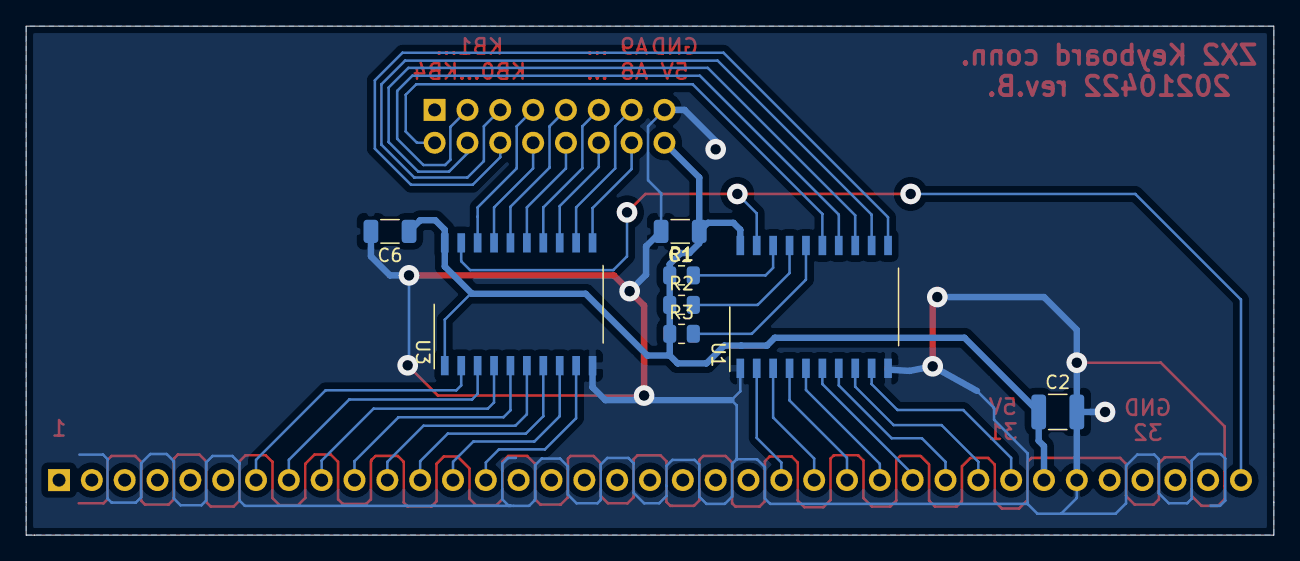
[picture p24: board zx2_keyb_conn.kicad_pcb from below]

Board: 2 copper layers, 96.5 x 39.4 mm, 10 parts (8 on the bottom side), 35 nets.

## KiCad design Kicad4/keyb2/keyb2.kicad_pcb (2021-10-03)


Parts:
C1: 10u; C_1210_HandSoldering
C2: 100n; C_1206_HandSoldering
D1, D2, D3, D4, D5, D6, D7, D8: D; R_0805_HandSoldering
J1: PWR; Pin_Header_Straight_2x03_Pitch2.54mm_SMD
J2: GND; Pin_Header_Straight_2x02_Pitch2.54mm_SMD
J3: KB; Pin_Header_Straight_2x03_Pitch2.54mm_SMD
J4: ADDR; Pin_Header_Straight_2x04_Pitch2.54mm_SMD
R1, R2, R3, R4, R5: 10k; R_0805_HandSoldering
SW1: SW_1; SW_SPST_EVQQ2
SW2: SW_Q; SW_SPST_EVQQ2
SW3: SW_A; SW_SPST_EVQQ2
SW4: SW_CAPS; SW_SPST_EVQQ2
SW5: SW_2; SW_SPST_EVQQ2
SW6: SW_W; SW_SPST_EVQQ2
SW7: SW_S; SW_SPST_EVQQ2
SW8: SW_Z; SW_SPST_EVQQ2
SW9: SW_3; SW_SPST_EVQQ2
SW10: SW_E; SW_SPST_EVQQ2
SW11: SW_D; SW_SPST_EVQQ2
SW12: SW_X; SW_SPST_EVQQ2
SW13: SW_4; SW_SPST_EVQQ2
SW14: SW_R; SW_SPST_EVQQ2
SW15: SW_F; SW_SPST_EVQQ2
SW16: SW_C; SW_SPST_EVQQ2
SW17: SW_5; SW_SPST_EVQQ2
SW18: SW_T; SW_SPST_EVQQ2
SW19: SW_G; SW_SPST_EVQQ2
SW20: SW_V; SW_SPST_EVQQ2
SW21: SW_6; SW_SPST_EVQQ2
SW22: SW_Y; SW_SPST_EVQQ2
SW23: SW_H; SW_SPST_EVQQ2
SW24: SW_B; SW_SPST_EVQQ2
SW25: SW_7; SW_SPST_EVQQ2
SW26: SW_U; SW_SPST_EVQQ2
SW27: SW_J; SW_SPST_EVQQ2
SW28: SW_N; SW_SPST_EVQQ2
SW29: SW_8; SW_SPST_EVQQ2
SW30: SW_I; SW_SPST_EVQQ2
SW31: SW_K; SW_SPST_EVQQ2
SW32: SW_M; SW_SPST_EVQQ2
SW33: SW_9; SW_SPST_EVQQ2
SW34: SW_O; SW_SPST_EVQQ2
SW35: SW_L; SW_SPST_EVQQ2
SW36: SW_SYM; SW_SPST_EVQQ2
SW37: SW_0; SW_SPST_EVQQ2
SW38: SW_P; SW_SPST_EVQQ2
SW39: SW_ENT; SW_SPST_EVQQ2
SW40: SW_SP; SW_SPST_EVQQ2

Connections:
+5V: C1.1, C2.1, J1.1, J1.3, J1.5, R1.1, R2.1, R3.1, R4.1, R5.1
/A8: D4.1 (K), J4.1
/A9: D3.1 (K), J4.2
/A10: D2.1 (K), J4.3
/A11: D1.1 (K), J4.4
/A12: D5.1 (K), J4.5
/A13: D6.1 (K), J4.6
/A14: D7.1 (K), J4.7
/A15: D8.1 (K), J4.8
/KB0: J3.1, R1.2, SW1.1, SW2.1, SW3.1, SW4.1, SW37.1, SW38.1, SW39.1, SW40.1
/KB1: J3.2, R2.2, SW5.1, SW6.1, SW7.1, SW8.1, SW33.1, SW34.1, SW35.1, SW36.1
/KB2: J3.3, R3.2, SW9.1, SW10.1, SW11.1, SW12.1, SW29.1, SW30.1, SW31.1, SW32.1
/KB3: J3.4, R4.2, SW13.1, SW14.1, SW15.1, SW16.1, SW25.1, SW26.1, SW27.1, SW28.1
/KB4: J3.5, R5.2, SW17.1, SW18.1, SW19.1, SW20.1, SW21.1, SW22.1, SW23.1, SW24.1
GND: C1.2, C2.2, J1.2, J1.4, J1.6, J2.1, J2.2, J2.3, J2.4
unnamed: D1.2 (A), SW1.2, SW5.2, SW9.2, SW13.2, SW17.2
unnamed: D2.2 (A), SW2.2, SW6.2, SW10.2, SW14.2, SW18.2
unnamed: D3.2 (A), SW3.2, SW7.2, SW11.2, SW15.2, SW19.2
unnamed: D4.2 (A), SW4.2, SW8.2, SW12.2, SW16.2, SW20.2
unnamed: D5.2 (A), SW21.2, SW25.2, SW29.2, SW33.2, SW37.2
unnamed: D6.2 (A), SW22.2, SW26.2, SW30.2, SW34.2, SW38.2
unnamed: D7.2 (A), SW23.2, SW27.2, SW31.2, SW35.2, SW39.2
unnamed: D8.2 (A), SW24.2, SW28.2, SW32.2, SW36.2, SW40.2


Board: 2 copper layers, 177.2 x 103.8 mm, 59 parts (0 on the bottom side), 23 nets.

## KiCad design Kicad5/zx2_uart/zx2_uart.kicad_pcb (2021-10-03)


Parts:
C1: 10u; C_1210_3225Metric
C2, C3: 22p; C_0603_1608Metric
C4: 10n; C_1206_3216Metric
C5: 100n; C_1206_3216Metric
D1: TX_LED; D_0805_2012Metric
D2: RX_LED; D_0805_2012Metric
J1: USB_B_Micro; USB_Micro-B_Amphenol_10104110_Horizontal
J2: CONN; PinHeader_1x06_P2.54mm_Vertical
R1, R2, R3, R4: 1k; R_0805_2012Metric
U1: CH340G; SOIC-16_3.9x9.9mm_P1.27mm
Y1: 12MHz; Crystal_SMD_3225-4Pin_3.2x2.5mm

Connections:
+5V: C1.1, C5.2, J1.1 (VBUS), J2.1, R3.2, R4.2, U1.16 (VCC)
/RX: D2.1 (K), J2.4, R2.1
/TX: D1.1 (K), J2.3, R1.1
/~CTS: J2.6, U1.9 (~CTS)
/~RTS: J2.5, U1.14 (~RTS)
GND: C1.2, C2.1, C3.1, C4.2, C5.1, J1.5 (GND), J2.2, U1.1 (GND), Y1.2, Y1.4
unnamed: C2.2, U1.7 (XI), Y1.1
unnamed: C3.2, U1.8 (XO), Y1.3
unnamed: C4.1, U1.4 (V3)
unnamed: D1.2 (A), R3.1
unnamed: D2.2 (A), R4.1
unnamed: J1.2 (D-), U1.6 (UD-)
unnamed: J1.3 (D+), U1.5 (UD+)
unnamed: R1.2, U1.2 (TXD)
unnamed: R2.2, U1.3 (RXD)


Board: 2 copper layers, 15 parts (0 on the bottom side), 15 nets.

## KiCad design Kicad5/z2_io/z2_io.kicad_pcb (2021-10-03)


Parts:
C1, C3, C5, C6, C7, C8, C9: 100n; C_1206_3216Metric
C2: 10u; C_1210_3225Metric
D2, D3, D4, D5, D6, D7, D8, D9, D10, D11, D12, D13, D14, D15, D16, D17: LED; D_0805_2012Metric
F1: Fuse; Fuse_1812_4532Metric
J1: KB_SEL; PinHeader_2x02_P2.54mm_Vertical
J2: CONN; PinHeader_1x37_P2.54mm_Horizontal
J3: UART_A; PinHeader_1x06_P2.54mm_Horizontal
J4: UART_B; PinHeader_1x06_P2.54mm_Horizontal
J5: PW_SEL; PinHeader_2x02_P2.54mm_Vertical
J6: CONN_OUT; PinHeader_2x04_P2.54mm_Vertical
J7: LED_EN; PinHeader_1x02_P2.54mm_Vertical
R2, R3, R4, R5, R6, R7, R8, R9, R10, R11, R12, R13, R14, R15, R16, R17, R18, R19, R20, R21, R22, R23, R24, R25: R; R_0805_2012Metric
SW1: DIP_SW_C; DIP-16_W7.62mm
U1: 74LS154; DIP-24_W7.62mm
U3: 74HC245; DIP-20_W7.62mm
U4, U9: 74LS32; DIP-14_W7.62mm
U5: Z8440; DIP-40_W15.24mm
U6, U8: 74HC374; DIP-20_W7.62mm
U7: 74LVC1G14; SOT-353_SC-70-5

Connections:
/1F_PORT_CK: J6.2, U9.3
/3F_PORT_CK: J6.4, U9.6
/5F_PORT_CK: J6.6, U9.8
/5V: C1.1, C2.1, C3.1, C5.1, C6.1, C7.1, C8.1, C9.1, F1.2, J2.31, R2.1, R3.1, R4.1, R5.1, R6.1, R7.1, R8.1, R9.1, U1.24 (VCC), U3.20 (VCC), U4.14 (VCC), U5.9 (VCC), U6.20 (VCC), U7.5 (VCC), U8.20 (VCC), U9.14 (VCC)
/5V_UART_A: J3.1, J5.2
/5V_UART_B: J4.1, J5.4
/7F_PORT_CK: J6.8, U9.11
/A0: J1.1, J2.22, U1.23 (A0)
/A1: J2.21, U5.33 (C/~D)
/A2: J2.20, U5.34 (B/~A)
/A5: J2.17, U1.22 (A1)
/A6: J2.16, U1.21 (A2)
/A7: J2.15, U1.20 (A3)
/CLK: J2.33, U4.4, U4.9, U5.20 (CLK), U9.2, U9.5, U9.10, U9.13
/CLK2: J2.34, U5.13 (~RxCA), U5.14 (~TxCA), U5.27 (~TxRxCB)
/D0: J2.30, U3.2 (A0), U5.40 (D0), U6.3 (D0), U8.3 (D0)
/D1: J2.29, U3.3 (A1), U5.1 (D1), U6.4 (D1), U8.4 (D1)
/D2: J2.28, U3.4 (A2), U5.39 (D2), U6.7 (D2), U8.7 (D2)
/D3: J2.27, U3.5 (A3), U5.2 (D3), U6.8 (D3), U8.8 (D3)
/D4: J2.26, U3.6 (A4), U5.38 (D4), U6.13 (D4), U8.13 (D4)
/D5: J2.25, U3.7 (A5), U5.3 (D5), U6.14 (D5), U8.14 (D5)
/D6: J2.24, U3.8 (A6), U5.37 (D6), U6.17 (D6), U8.17 (D6)
/D7: J2.23, U3.9 (A7), U5.4 (D7), U6.18 (D7), U8.18 (D7)
/GND: C1.2, C2.2, C3.2, C5.2, C6.2, C7.2, C8.2, C9.2, J2.32, J3.2, J4.2, J7.2, SW1.9, SW1.10, SW1.11, SW1.12, SW1.13, SW1.14, SW1.15, SW1.16, U1.12 (GND), U3.1 (A->B), U3.10 (GND), U4.7 (GND), U5.6 (IEI), U5.31 (GND), U6.1 (OE), U6.10 (GND), U7.3 (GND), U8.1 (OE), U8.10 (GND), U9.7 (GND)
/M1: U1.19 (E1), U7.4
/RX_A: J3.4, U5.15 (TXDA)
/RX_B: J4.4, U5.26 (TXDB)
/TX_A: J3.3, U5.12 (RXDA)
/TX_B: J4.3, U5.28 (RXDB)
/~1F_PORT: J6.1, U1.2 (S1), U9.1
/~3F_PORT: J6.3, U1.4 (S3), U9.4
/~5F_PORT: J6.5, U1.6 (S5), U9.9
/~7F_PORT: J6.7, U1.8 (S7), U9.12
/~9F_PORT: U1.10 (S9), U4.5
/~BF_PORT: U1.13 (S11), U4.10
/~CTS_A: J3.6, U5.17 (~RTSA)
/~CTS_B: J4.6, U5.24 (~RTSB)
/~DF_PORT: U1.15 (S13), U3.19 (CE)
/~FE_PORT: J1.3, U1.16 (S14)
/~FF_PORT: U1.17 (S15), U5.35 (~CE)
/~IORQ: J2.2, U1.18 (E0), U5.36 (~IORQ)
/~KBEN: J2.37, U4.3
/~M1: J2.6, U5.8 (~M1), U7.2
/~RD: J2.3, U4.1, U5.32 (~RD)
/~RESET: J2.36, U5.21 (~RESET)
/~RTS_A: J3.5, U5.18 (~CTSA)
/~RTS_B: J4.5, U5.23 (~CTSB)
unnamed: D2.2 (A), R10.1
unnamed: D3.2 (A), R11.1
unnamed: D4.2 (A), R14.1
unnamed: D5.2 (A), R15.1
unnamed: D6.2 (A), R18.1
unnamed: D7.2 (A), R19.1
unnamed: D8.2 (A), R22.1
unnamed: D9.2 (A), R23.1
unnamed: D2.1 (K), D3.1 (K), D4.1 (K), D5.1 (K), D6.1 (K), D7.1 (K), D8.1 (K), D9.1 (K), D10.1 (K), D11.1 (K), D12.1 (K), D13.1 (K), D14.1 (K), D15.1 (K), D16.1 (K), D17.1 (K), J7.1
unnamed: D10.2 (A), R12.1
unnamed: D11.2 (A), R13.1
unnamed: D12.2 (A), R16.1
unnamed: D13.2 (A), R17.1
unnamed: D14.2 (A), R20.1
unnamed: D15.2 (A), R21.1
unnamed: D16.2 (A), R24.1
unnamed: D17.2 (A), R25.1
unnamed: F1.1, J5.1, J5.3
unnamed: J1.2, J1.4, U4.2
unnamed: R2.2, SW1.8, U3.11 (B7)
unnamed: R3.2, SW1.7, U3.12 (B6)
unnamed: R4.2, SW1.6, U3.13 (B5)
unnamed: R5.2, SW1.5, U3.14 (B4)
unnamed: R6.2, SW1.4, U3.15 (B3)
unnamed: R7.2, SW1.3, U3.16 (B2)
unnamed: R8.2, SW1.2, U3.17 (B1)
unnamed: R9.2, SW1.1, U3.18 (B0)
unnamed: R10.2, U6.2 (O0)
unnamed: R11.2, U6.12 (O4)
unnamed: R12.2, U8.2 (O0)
unnamed: R13.2, U8.12 (O4)
unnamed: R14.2, U6.5 (O1)
unnamed: R15.2, U6.15 (O5)
unnamed: R16.2, U8.5 (O1)
unnamed: R17.2, U8.15 (O5)
unnamed: R18.2, U6.6 (O2)
unnamed: R19.2, U6.16 (O6)
unnamed: R20.2, U8.6 (O2)
unnamed: R21.2, U8.16 (O6)
unnamed: R22.2, U6.9 (O3)
unnamed: R23.2, U6.19 (O7)
unnamed: R24.2, U8.9 (O3)
unnamed: R25.2, U8.19 (O7)
unnamed: U4.6, U6.11 (Cp)
unnamed: U4.8, U8.11 (Cp)

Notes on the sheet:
Podłączenie na przemian: TX-RX CTS-RTS
Założenie: wszystkie nieistotne bity są ustawione na 1
Błąd - nie A0, ale A0 or ~IORQ~ !!!



Board: 2 copper layers, 104.8 x 101.0 mm, 65 parts (11 on the bottom side), 92 nets.

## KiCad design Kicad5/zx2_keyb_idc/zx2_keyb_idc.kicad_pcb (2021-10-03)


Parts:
J1: KB_CONN; PinHeader_2x08_P2.54mm_Vertical_SMD
J2: KB_CONN_PWR; PinHeader_2x03_P2.54mm_Vertical
J3: KB_CONN_ADDR; PinHeader_2x04_P2.54mm_Vertical
J4: KB_CONN_D; PinHeader_2x03_P2.54mm_Vertical

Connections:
/5V: J1.16, J2.2, J2.4, J2.6
/A8K: J1.14, J3.8
/A9K: J1.13, J3.7
/A10K: J1.12, J3.6
/A11K: J1.11, J3.5
/A12K: J1.10, J3.4
/A13K: J1.9, J3.3
/A14K: J1.8, J3.2
/A15K: J1.7, J3.1
/GND: J1.15, J2.1, J2.3, J2.5
/KB0: J1.6, J4.6
/KB1: J1.5, J4.5
/KB2: J1.4, J4.4
/KB3: J1.3, J4.3
/KB4: J1.2, J4.2


Board: 2 copper layers, 71.1 x 21.6 mm, 4 parts (0 on the bottom side), 15 nets.
